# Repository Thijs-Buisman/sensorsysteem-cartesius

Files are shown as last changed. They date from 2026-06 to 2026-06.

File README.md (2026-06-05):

# Sensorsysteem – Wijk Cartesius, Utrecht

> Automatisch passantentelsysteem op basis van een lasersensor met fotodiode.  
> Ontwikkeld in het kader van het QUEST-project **"Gezond leven in Cartesius"** – Hogeschool Utrecht, 2026.

---

## Wat doet dit systeem?

Dit systeem telt automatisch hoeveel voetgangers, fietsers en auto's er door een doorgang in de wijk Cartesius (Utrecht) passeren. De data wordt lokaal opgeslagen op een SD-kaart als CSV-bestand, voorzien van een tijdstempel via een RTC-module.

Het systeem bestaat uit twee onderdelen:
- **Zender** – een lasermodule die een onzichtbare laserstraal uitzendt
- **Ontvanger** – een fotodiode die registreert wanneer de laserstraal wordt onderbroken

Wanneer iemand de straal onderbreekt, classificeert het systeem de passage als voetganger, fietser of auto op basis van de duur en het patroon van de onderbreking.

---

## Resultaten veldtest (21 mei 2026)

| Gebruikerstype | Sensor | Handmatig | Afwijking |
|---|---|---|---|
| Voetganger | 50 | 47 | 6,4% |
| Fietser | 28 | 32 | 12,5% |
| Auto | 3 | 0 | – |
| **Totaal** | **81** | **79** | **2,5%**  |

Totale afwijking: **2,5%** — ruim binnen de gestelde eis van maximaal 15%.

---

## Inhoud van deze repository

```
sensorsysteem-cartesius/
│
├── code/
│   ├── Sensor_code_V3.ino       # Definitieve sensorcode (gebruik deze)
│   └── Sensor_code_V2.ino       # Vorige versie, ter referentie
│
├── kicad/
│   ├── PCB_sensor/              # KiCad 9.0 project – sensorprintplaat (ontvanger)
│   └── PCB_laser/               # KiCad 9.0 project – laserprintplaat (zender)
│
├── 3d-ontwerp/                    # STL-bestanden en .itp autodesk inventor van alle 7 behuizingsonderdelen
│
├── testdata/
│   ├── 05201342.CSV        # Ruwe sensordata van de veldtest
│   └── Sensor_validatie_test.xlsx     # Vergelijking sensor vs. handmatige telling
│
└── docs/
    ├── Overdracht_Sensorsysteem_Cartesius.pdf   # Overdrachts document (begin hier)
    ├── Handleiding_Sensorprototype.pdf
    ├── Proof_of_Concept_Sensorsysteem.pdf
    └── PCB-ontwerp_sensor_V1.pdf
```

---

## Benodigde hardware

| Component | Type | Kosten (ca.) |
|---|---|---|
| Microcontroller | Arduino Nano | €4,00 |
| Lasermodule | KY-008 | €1,50 |
| Fotodiode | SGPD5051C6 | €3,50 |
| RTC-module | DS3231 | €4,00 |
| SD-kaartmodule | standaard SPI | €2,50 |
| Protoboard + bedrading | – | €5,00 |
| 3D-print materiaal | PLA, 573 gram | €12,00 |
| Powerbanks (2x) | 5V USB | €20,00 |
| **Totaal** | | **~€83,92** |

---

## Benodigde software

- [Arduino IDE](https://www.arduino.cc/en/software) – voor de sensorcode
- [KiCad 9.0](https://www.kicad.org/) – voor de PCB-schema's en layouts
- [PrusaSlicer](https://www.prusa3d.com/page/prusaslicer_424/) of [Cura](https://ultimaker.com/software/ultimaker-cura/) – voor de 3D-print bestanden
- [Autodesk Inventor](https://www.autodesk.com/nl/products/inventor/overview) - 3D-modelleringssoftware voor ontwerpers en ingenieurs

---

## Snel aan de slag

1. Download of clone deze repository
2. Open `docs/Overdrachts_document_Sensorsysteem_Cartesius.docx` — dit is het startpunt
3. Upload `code/Sensor_code_V3.ino` via Arduino IDE naar een Arduino Nano
4. Volg de plaatsingsinstructies in `docs/Handleiding_Sensorprototype.docx`

---

## Project & opleiding

| | |
|---|---|
| **Project** | Gezond leven in Cartesius |
| **Opdrachtgever** | Hanneke Kruize – Lectoraat Building Future Cities (RAAK PRO) |
| **Opleiding** | GCL/IDE · QUEST 30EC · Hogeschool Utrecht |
| **Auteur** | Thijs Buisman · Studentnummer 1855662 |
| **Groep** | Groep 8 (Boas Janssen, Joost, Kim, Melisa, Stef, Thijs Buisman) |
| **Docentcoach** | Marit Béguin |
| **Jaar** | 2025–2026 |

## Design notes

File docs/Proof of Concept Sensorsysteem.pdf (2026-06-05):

## Proof of Concept Sensorsysteem

Thijs Buisman 1855662 HU

1. Aanleiding en keuze voor de lasersensor
Binnen het onderzoek naar het gebruik van de buitenruimte in de wijk Cartesius was er behoefte aan een methode om passanten continu en objectief te tellen. De handmatige observatiemethode SOPARC levert waardevolle data op, maar is arbeidsintensief en beperkt tot momentopnames. Daarom is onderzocht of sensortechnologie dit proces kon automatiseren.

Bij de keuze voor een geschikte meettechniek zijn meerdere alternatieven overwogen:
- Camera met computer vision: betrouwbaar en nauwkeurig, maar maakt beeldopnames van mensen. Dit stuit op privacybezwaren en is niet AVG-proof voor gebruik in de openbare ruimte.
- PIR-sensor (bewegingssensor): goedkoop en eenvoudig, maar te ongericht. Reageert op warmte en beweging zonder onderscheid te maken tussen verschillende gebruikerstypen.
- Ultrasone sensor (HC-SR04): geschikt voor afstandsmeting, maar minder betrouwbaar bij smalle doorgangen met meerdere passanten tegelijk.
- Lasersensor met fotodiode: nauwkeurig, AVG-proof (geen beeldopname), kostenefficiënt en geschikt voor het detecteren van patronen per gebruikerstype.

De keuze is gevallen op het lasersysteem. Dit systeem werkt volledig anoniem er worden geen beelden gemaakt en geen persoonsgegevens opgeslagen wat aansluit bij de privacy-eisen die gelden voor onderzoek in een woonwijk.

De werking van het systeem is schematisch weergegeven in Figuur 1. Hierin is te zien hoe de laserstraal tussen de laserbron en de fotodetector loopt, en hoe verschillende gebruikerstypen (wandelaar, fietser en auto) elk een herkenbaar onderbrekingspatroon veroorzaken.

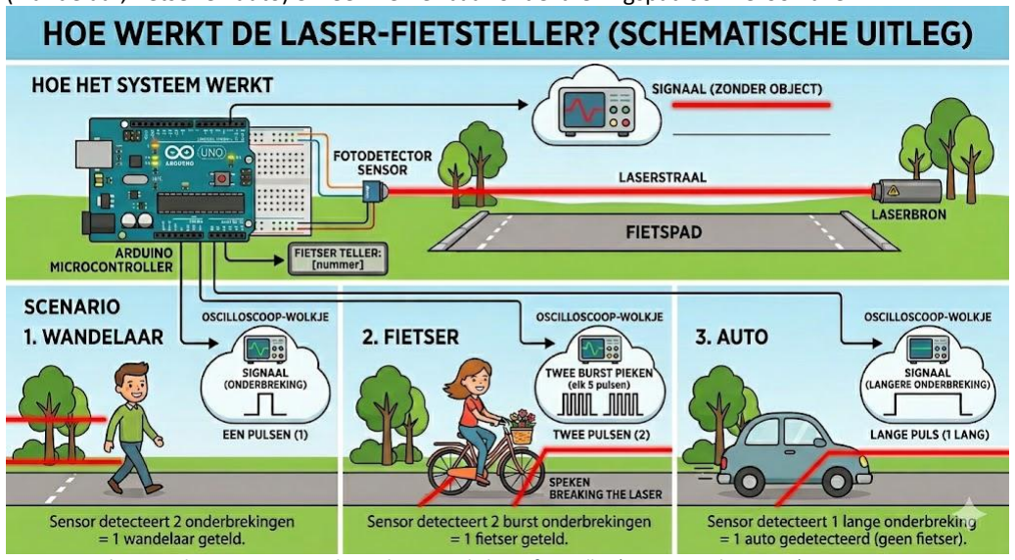
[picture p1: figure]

Figuur 1 - Schematische weergave van de werking van de laser-fietsteller (Bron: nano banana 2)

2. Systeemeisen
Om te kunnen beoordelen of het prototype voldoet aan de gestelde verwachtingen, zijn vooraf systeemeisen opgesteld. Deze eisen zijn geprioriteerd volgens de MoSCoW-methode zo als te zien is in Tabel 1.

Tabel 1 – Eisenlijst sensorsysteem

MoSCoW | Eis
Must have | Het systeem detecteert een onderbreking van de laserstraal betrouwbaar bij minimaal 2 meter afstand tussen laser en fotodiode.
Must have | Elke detectie wordt opgeslagen met een correcte tijdstempel (datum en tijd) op de SD-kaart.
Must have | Het systeem onderscheidt minimaal drie gebruikerstypen: voetganger, fietser en auto.
Must have | Het systeem werkt minimaal 8 uur aaneengesloten op een powerbank van 5000 mAh.
Should have | Het systeem werkt betrouwbaar bij direct zonlicht zonder valse detecties.
Should have | De foutmarge ten opzichte van handmatige telling bedraagt maximaal 15%.
Should have | Het systeem logt geen dubbeltellingen bij één passage.
Could have | Het systeem detecteert de looprichting van een passant.
Could have | De data wordt automatisch geëxporteerd naar een leesbaar CSV-bestand met kolomkoppen.
Won't have | Draadloze datatransmissie (WiFi/LoRa).
Won't have | Realtime monitoring op afstand.
Won't have | Automatische classificatie via machine learning.

3. Componentenkeuze en kostenoverzicht
Op basis van de gekozen meettechniek zijn de benodigde componenten geselecteerd. Daarbij is gelet op beschikbaarheid, prijs en geschiktheid voor buiteninzet. Bewust is gekozen voor een opstelling zonder draadloze verbinding, zodat het systeem volledig zelfstandig functioneert en niet afhankelijk is van een netwerkverbinding. Onderstaande Tabel 2 toont een overzicht van alle onderdelen en de bijbehorende kosten.

Tabel 2 - Kostenoverzicht ontwikkeling prototype

Onderdeel | Specificatie | Kosten
Arduino Nano | Microcontroller voor de verwerking | € 9,99
Laser module KY-008 | Laserbron voor de straalonderbreking | € 1,50
Clock module DS3231 | 2 stuks (voor exacte tijdsregistratie) | € 5,40
Mini SD module | SPI interface voor data-opslag | € 2,27
Micro-SD Kaart 32GB | Lokale data-opslag | € 17,99
Photodiode SGPD5051C6 | 5mm flat lens (detectie van de straal) | € 1,85
Weerstand kit | Diverse componenten voor circuit | € 2,50
Kabel rood/zwart | Solid core 0,25 mm (25m) | € 0,79
Solder board | 2 stuks voor montage | € 1,40
3D print filament | 150 gram (voor behuizing) | € 2,25
Powerbank | 2 stuks (5000 mAh) voor voeding | € 37,98
Totaal | | € 83,92

Opmerking: verzendkosten zijn niet meegenomen omdat een deel van de componenten al in eigen bezit was.

4. Aansluiting en opbouw van het circuit

4.1 Test op breadboard
Voordat de componenten definitief werden gesoldeerd, is de volledige schakeling eerst opgebouwd op een breadboard. Dit maakt het eenvoudig om aansluitingen te testen en fouten te corrigeren zonder schade aan de onderdelen. Tijdens de breadboard-fase is gecontroleerd of:
- De fotodiode het lasersignaal correct ontvangt en verwerkt.
- De RTC-module de juiste tijd doorgeeft aan de Arduino.
- De SD-kaartmodule data wegschrijft zonder fouten.
- De Arduino Nano de signalen correct interpreteert en logt.

Tijdens deze fase is ook een belangrijk probleem ontdekt met de aansluiting van de fotodiode. Eerst was de fotodiode aangesloten op digitale pin D2 met een 1MΩ pull-down weerstand naar GND. Binnen werkte dit correct, maar buiten in direct zonlicht zag het systeem continu een laser terwijl die er niet was. De hoge weerstandswaarde maakte de fotodiode te gevoelig voor omgevingslicht. Dit is opgelost door over te stappen op een 10kΩ pull-down weerstand en de fotodiode aan te sluiten op analoge pin A3. Hierdoor kon in de code een drempelwaarde worden ingesteld waarboven een signaal pas als laser wordt gedetecteerd.

De breadboard-opstelling is te zien in Figuur 2.

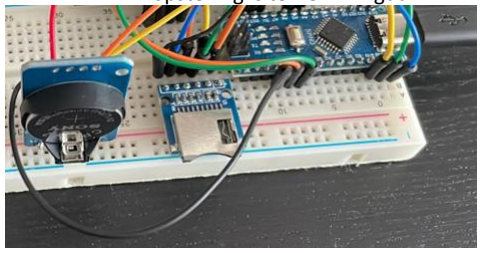
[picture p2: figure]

Figuur 2 – Test sensor schakling op breabord.

4.2 Schematisch ontwerp in KiCad
Het aansluitschema is uitgewerkt in KiCad. Dit schema toont hoe de Arduino Nano, de RTC-module (DS3231), de SD-kaartmodule en de fotodiode op elkaar zijn aangesloten. De schematische weergave is te zien in Figuur 3.

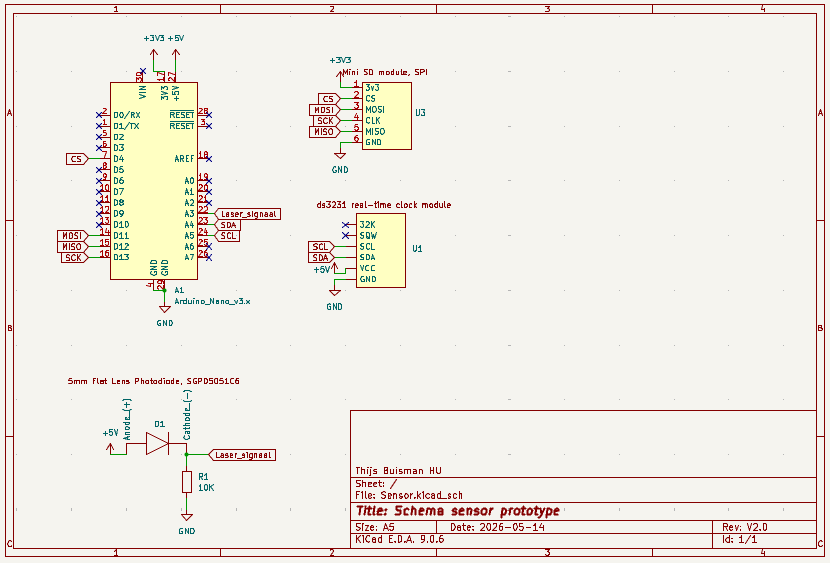
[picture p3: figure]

Figuur 3 - Schema sensor prototype in KiCad

Belangrijkste aansluitingen:
- Fotodiode → analoge ingang A3 van de Arduino Nano, met een 10kΩ pull-down weerstand naar GND.
- RTC DS3231 → I2C-bus (SDA op A4, SCL op A5).
- SD-kaartmodule → SPI-bus (MOSI op D11, MISO op D12, SCK op D13, CS op D10).
- Voeding → 5V en GND van de powerbank via USB naar de Arduino, die de overige modules voedt.

4.3 Solderen op protoboard
Na goedkeuring van het schema zijn de componenten gesoldeerd op een soldeerbordje (protoboard). Hierbij is gebruikgemaakt van solid core kabel (0,25 mm) voor vaste verbindingen. Tijdens het solderen deed zich een complicatie voor: twee RTC DS3231-modules bleken defect te zijn na het solderen. Dit heeft ertoe geleid dat de klokmodule twee keer opnieuw gesoldeerd en vervangen moest worden voordat het systeem correct functioneerde. Dit benadrukt het belang van het testen van componenten vóór definitieve montage. Het gesoldeerde protoboard is te zien in Figuur 4

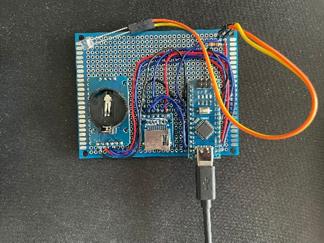
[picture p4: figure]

Figuur 4 - Sensor schakling op protoboard.

5. Behuizing
Voor de behuizing van het sensorsysteem is een modulair ontwerp gekozen. Zowel de zender (laser) als de ontvanger (fotodiode met protoboard) bestaan elk uit vijf onderdelen, waarvan drie identiek zijn. Dit betekent dat deze drie onderdelen onderling verwisselbaar zijn, wat het systeem eenvoudiger maakt om te produceren en te onderhouden.

De gedeelde onderdelen zijn de prikker, het tussenstuk en de sensorhouder. De behuizing zelf verschilt per module omdat de ruimte-inwendige eisen anders zijn. Een overzicht van alle onderdelen van de behuizing is te zien in Figuur 5.

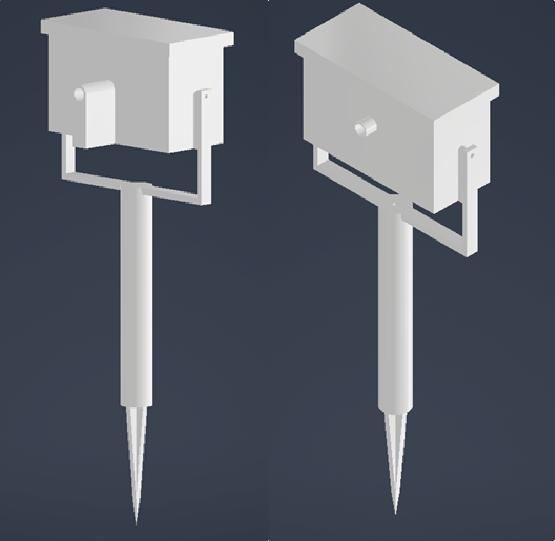
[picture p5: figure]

Figuur 5 - Overzicht van alle onderdelen van de behuizing

Onderdeel 1 - De prikker
De prikker is een spits toelopend onderdeel dat in de grond wordt gestoken, vergelijkbaar met de pennen van buitenlampen zo als te zien is in Figuur 6. Dit zorgt voor een stabiele en rechte plaatsing in de buitenomgeving zonder dat er geboord of geschroefd hoeft te worden in bestaande constructies.

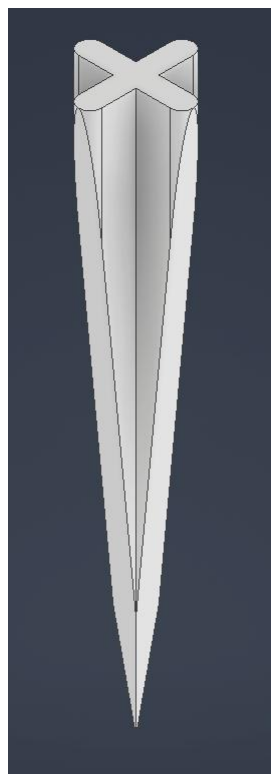
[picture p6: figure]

Figuur 6 - De prikker

Onderdeel 2 - Het tussenstuk
Het tussenstuk is cilindrisch van vorm en verbindt de prikker met de rest van de opstelling zo als te zien is in Figuur 7. Het zorgt ervoor dat de zender en ontvanger op de juiste hoogte komen te staan om ook auto's betrouwbaar te kunnen detecteren. Aan de onderkant past de prikker in het tussenstuk. Aan de bovenkant zit een gat voor een heat insert, zodat er een schroefdraadverbinding ontstaat waarmee de sensorhouder horizontaal verstelbaar is.

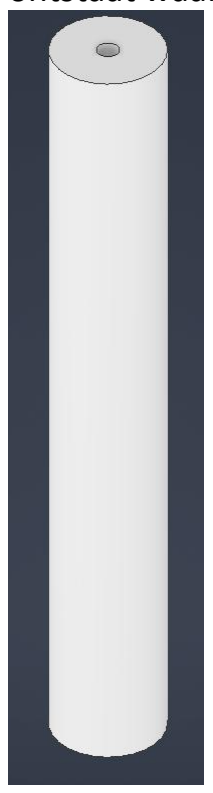
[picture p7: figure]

Figuur 7 - Het tussenstuk

Onderdeel 3 - De sensorhouder
De sensorhouder verbindt het tussenstuk met de behuizing van de sensor. Hij heeft drie gaten: twee voor de bevestiging aan het tussenstuk en één om de behuizing van de sensor zelf te kunnen kantelen. Door deze kantelverbinding kunnen zowel de zender als de ontvanger nauwkeurig op elkaar worden gericht, wat essentieel is voor een betrouwbare laserverbinding over langere afstanden. De sensorhouder is te zien in Figuur 8.

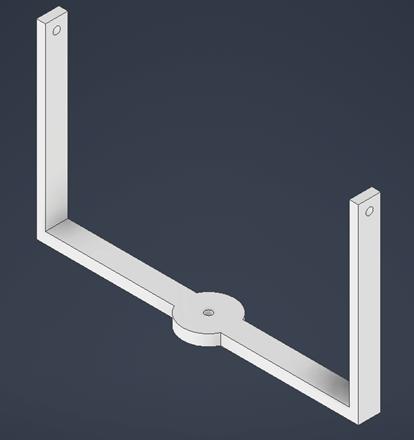
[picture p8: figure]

Figuur 8 - De sensorhouder

Onderdeel 4-5a - Behuizing ontvanger (fotodiode + protoboard)
De behuizing van de ontvanger is de grootste van de twee sensorbehuizingen. Aan de zijkant zitten twee gaten met heat inserts voor bevestiging aan de sensorhouder. De voorkant heeft een verlengde loop, vergelijkbaar met een kokertje, om direct invallend zonlicht zoveel mogelijk te weren. Dit vermindert valse detecties door omgevingslicht. Binnenin is ruimte voor de powerbank, het protoboard en de bedrading. Aan de onderkant zit een uitsparing waar een schakelaar in past om het systeem van stroom te voorzien. De behuizing wordt afgesloten met een passend deksel. De behuizing van de ontvanger is te zien in Figuur 9.

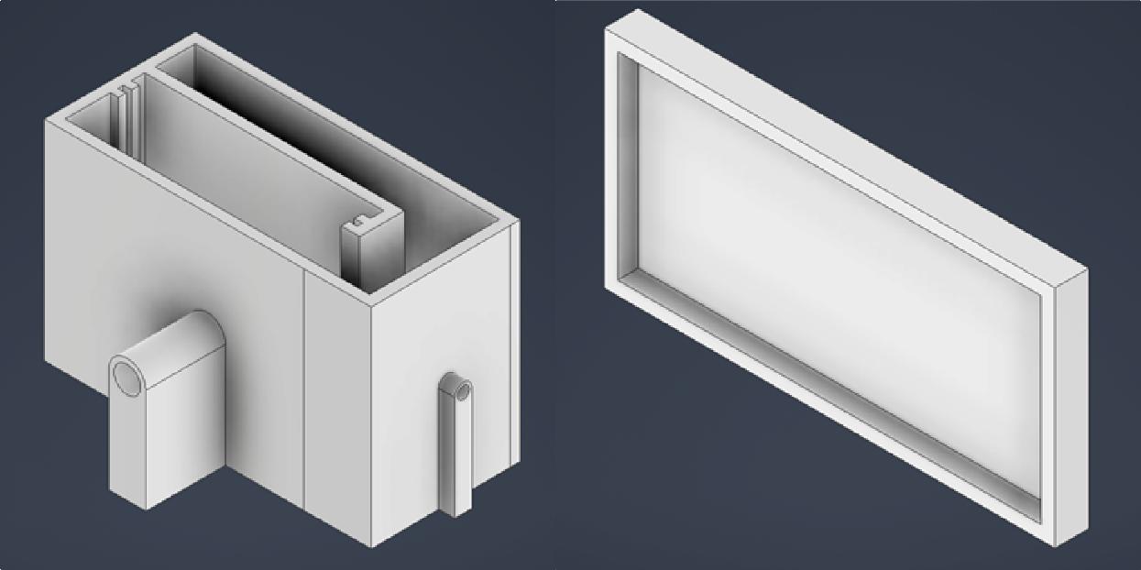
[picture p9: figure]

Figuur 9 - Behuizing ontvanger

Onderdeel 4-5b - Behuizing zender (laser)
De behuizing van de zender lijkt sterk op die van de ontvanger en heeft dezelfde bevestigingsgaten met heat inserts aan de zijkant. Omdat er alleen een lasermodule, een powerbank en een schakelaar in zitten, is deze behuizing compacter dan die van de ontvanger. Ook deze behuizing wordt afgesloten met een passend deksel. De behuizing van de zender is te zien in Figuur 10.

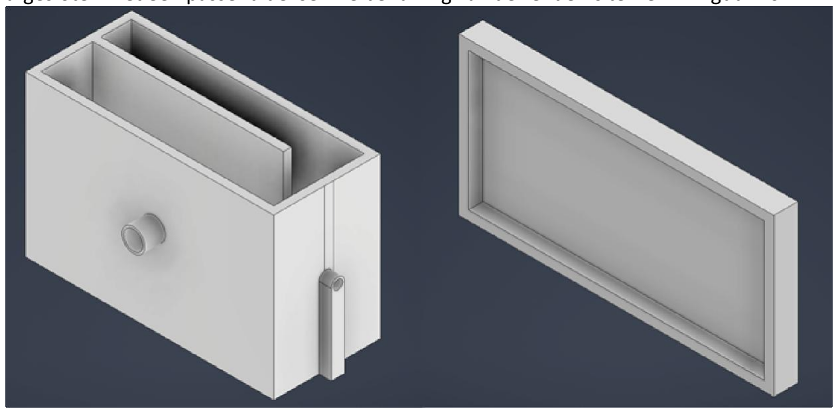
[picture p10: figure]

Figuur 10 - Behuizing zender

Ontwerpiteraties
Tijdens het 3D-printen van de behuizing zijn twee onderdelen aangepast op basis van praktische problemen die ontstonden bij de eerste printpoging.

Het tussenstuk (onderdeel 2) was in het oorspronkelijke ontwerp cilindrisch van vorm. De printer had moeite met het correct printen van deze ronde geometrie, waardoor het onderdeel niet bruikbaar uit de printer kwam. Als oplossing is de vorm aangepast van cilindrisch naar vierkant. Dit maakte het onderdeel beter printbaar zonder dat de functionaliteit verloren ging.

De sensorhouder (onderdeel 3) bleek na de eerste print te dun en daardoor niet sterk genoeg om de behuizing stabiel te houden. Om dit op te lossen is de wanddikte vergroot, waardoor het onderdeel voldoende stevigheid kreeg voor gebruik in de buitenomgeving.

De definitieve versie van alle onderdelen na deze aanpassingen is te zien in Figuur 11.

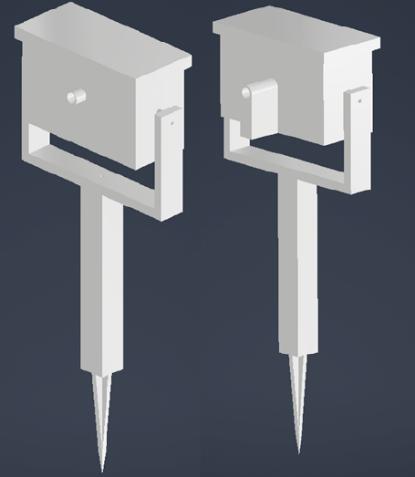
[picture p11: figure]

Figuur 11 - Definitieve onderdelen na ontwerpiteraties

Printoverzicht behuizing
Alle onderdelen zijn geprint met PLA-filament op een Ender V3 SE. Onderstaande Tabel 3 geeft een overzicht van het materiaalverbruik en de printtijd per onderdeel.

Tabel 3 - Printoverzicht behuizing

Onderdeel | Aantal | Materiaal per stuk (PLA) | Printtijd per stuk | Printer
Onderdeel 1 - De prikker | 2x | 8 gram | 1:31 uur | Ender V3 SE
Onderdeel 2 - Het tussenstuk | 2x | 52 gram | 3:00 uur | Ender V3 SE
Onderdeel 3 - De sensorhouder | 2x | 45 gram | 4:03 uur | Ender V3 SE
Onderdeel 4a - Behuizing ontvanger | 1x | 153 gram | 14:47 uur | Ender V3 SE
Onderdeel 4b - Behuizing zender | 1x | 140 gram | 13:19 uur | Ender V3 SE
Onderdeel 5a - Deksel ontvanger | 1x | 36 gram | 2:05 uur | Ender V3 SE
Onderdeel 5b - Deksel zender | 1x | 34 gram | 1:58 uur | Ender V3 SE
Totaal | 10 prints | 573 gram | ±49:17 uur | -

Resultaat
Na het printen en assembleren van alle onderdelen is het complete sensorsysteem tot stand gekomen. Onderstaande afbeelding Figuur 12 tonen het eindresultaat van zowel de zender als de ontvanger in de praktijk.

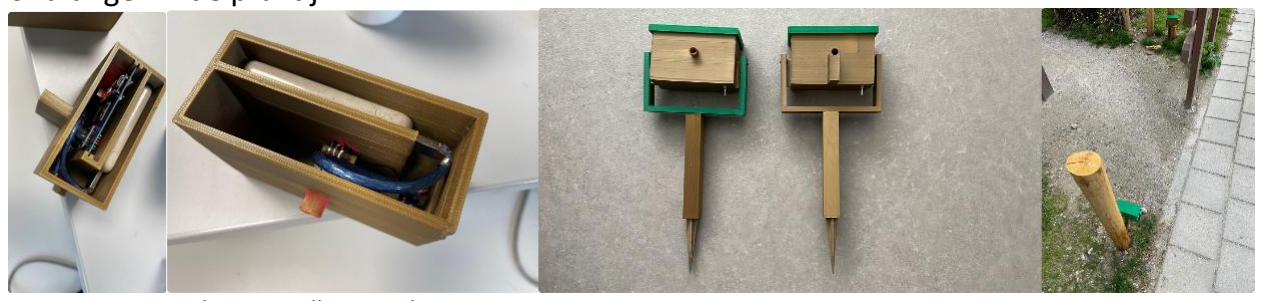
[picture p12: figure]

Figuur 12 - Complete opstelling zender en ontvanger

6. Ontwikkeling van de code

6.1 Losse component tests
Voordat de volledige code werd geschreven, zijn alle drie de modules eerst afzonderlijk getest in aparte Arduino-sketches. Voor de fotodiode is getest of de analoge waarden correct binnenkwamen via de Serial Monitor. De RTC DS3231 is getest op correcte tijdregistratie en de SD-kaartmodule is getest op het aanmaken en wegschrijven van een testbestand. Door componenten los te testen konden fouten per module worden opgespoord zonder dat andere onderdelen storing veroorzaakten.

6.2 Sensor Code V1 - eerste integratie
Na de losse tests zijn alle modules samengevoegd tot één werkende code: Sensor Code V1. De belangrijkste keuzes in V1 waren:
- De fotodiode was aangesloten op digitale pin D2 en werd uitgelezen met digitalRead().
- Het logbestand had een vaste naam: LOG.CSV.
- Detectie was gebaseerd op drie patronen: een lange onderbreking voor een auto, meerdere snelle onderbrekingen voor een fietser en een korte onderbreking voor een voetganger.

6.3 Sensor Code V2 - verbeteringen
Tijdens het testen van V1 buiten bleek dat de fotodiode te gevoelig was voor zonlicht, waardoor het systeem continu een laser registreerde terwijl die er niet was. Dit leidde tot de volgende verbeteringen in V2:
- Overstap van digitalRead() op analogRead() op pin A3, zodat een instelbare drempelwaarde (LASER_THRESHOLD) bepaalt wanneer de laser als aanwezig wordt beschouwd.
- Toevoeging van MIN_BREAK_DURATION om ruis en trillingen te filteren: onderbrekingen korter dan 20ms worden genegeerd.
- Het logbestand krijgt automatisch een naam op basis van datum en tijd van inschakelen, zodat meerdere meetmomenten te onderscheiden zijn.
- De sensorwaarde wordt nu ook geprint in de Serial Monitor voor eenvoudiger debuggen.

De werking van V2 is schematisch weergegeven in Figuur 13.

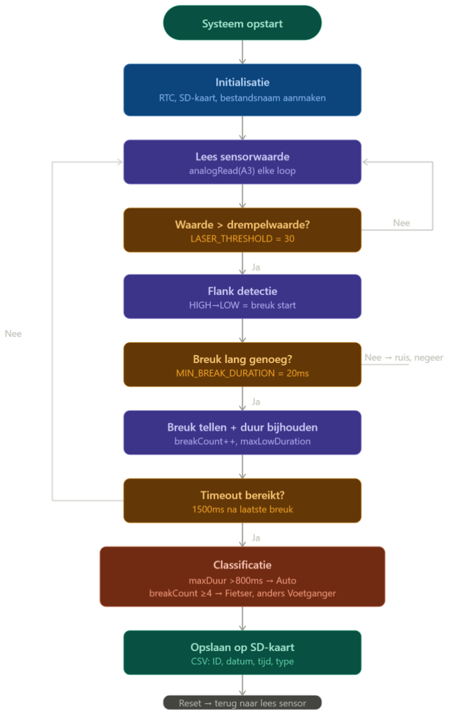
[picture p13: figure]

Figuur 13 - Flowchart sensor code v2

5.4 Sensor Code V3 - verbeterde code volgens richtlijnen
Na het ontwikkelen van V2 is de code herschreven naar V3 volgens de C-coding richtlijnen van de opleiding. De belangrijkste verbeteringen zijn:
- Alle constanten staan als #define bovenaan in hoofdletters, zodat direct zichtbaar is dat het om instellingen gaat.
- Elke functie heeft een documentatieblok met beschrijving, argumenten en returnwaarde.
- Bovenaan het bestand staat een volledige bestandsdocumentatie met naam, auteur, versie en beschrijving.
- De loop() functie bevat alleen nog functieaanroepen. Alle logica zit in aparte, herbruikbare functies.
- Globale variabelen beginnen met een g zodat direct zichtbaar is dat het globale variabelen zijn.
- Functieprototypes staan bovenaan zodat de volgorde van functies vrij is.
- Accolades staan lijnrecht onder elkaar met 4 spaties inspringing.

De code is opgesplitst in de volgende functies in Tabel 4:

Tabel 4 – Functies code

Functie | Beschrijving
initRTC() | Initialiseert de klokmodule
initSD() | Initialiseert de SD-kaartmodule
initLogFile() | Maakt logbestand aan met datum/tijd naam
readSensor() | Leest fotodiode en vergelijkt met drempelwaarde
handleBreakStart() | Verwerkt start van een laseronderbreking
handleBreakEnd() | Verwerkt einde van een onderbreking, filtert ruis
updateMaxDuration() | Houdt maximale breukduur bij
checkTimeout() | Controleert of evaluatiemoment bereikt is
classifyObject() | Classificeert passant als voetganger, fietser of auto
logData() | Schrijft detectie weg naar CSV op SD-kaart
resetMeting() | Reset alle variabelen voor volgende passage

De volledige code is te zien hieronder:

/*
*
=========================================================================== ==
* Sensor_code_V3.ino
* Auteur | : Thijs Buisman
* Versie | : 3.0
* Datum | : 2026
* -----------------------------------------------------------------------------
* Beschrijving:
* | Geautomatiseerd passantenmeetsysteem voor de buitenruimte van wijk
* | Cartesius. Het systeem detecteert onderbrekingen van een laserstraal
* | via een fotodiode en classificeert passanten als voetganger, fietser
* | of auto op basis van onderbrekingspatronen. Data wordt met tijdstempel
* | weggeschreven naar een CSV-bestand op een SD-kaart.
*
* Hardware:
* | - Arduino Nano
* | - Fotodiode op pin A3 met 10kOhm pull-down weerstand
* | - RTC DS3231 op I2C (SDA=A4, SCL=A5)
* | - SD-kaartmodule op SPI (MOSI=D11, MISO=D12, SKC=D13, CS=D4)
*
* Versiebeheer:
* | V1 - Eerste werkende integratie, digitalRead op D2
* | V2 - analogRead op A3, drempelwaarde, dynamische bestandsnaam
* | V3 - Modulaire opbouw, C-coding richtlijnen, functieprototypes

*
=========================================================================== ==
*/

#include <SPI.h>

#include <SD.h>

#include <Wire.h>

#include <RTClib.h>

/* --- Pin definities --- */
#define SENSOR_PIN | A3

#define SD_CS_PIN | 4

/* --- Sensor drempelwaarden --- */
#define LASER_THRESHOLD | 25 | /* Analoge waarde waarboven laser

aanwezig is */
#define MIN_BREAK_DURATION 20 | /* Minimale breukduur in ms, korter =

ruis | */

/* --- Detectie instellingen --- */
#define CAR_MIN_DURATION | 800 | /* Breukduur > 800ms =

auto | */
#define BIKE_MIN_INTERRUPTS 4 | /* 4 of meer breuken =

fietser | */
#define TIMEOUT_MS | 1500 /* Wachttijd na laatste breuk voor

evaluatie | */

/* --- Overige instellingen --- */
#define SENSOR_ID "0x001b"

#define CSV_HEADER "SensorID;Datum;Tijd;GedetecteerdObject"

/* --- Globale variabelen --- */
RTC_DS3231 | rtc;
char | gLogFile[13];
bool | gIsMeasuring;
bool | gLastSensorState;
unsigned long gCurrentLowStart; unsigned long gMaxLowDuration; unsigned long gLastInterruptTime;
int | gBreakCount;

/* --- Functieprototypes --- */
void | initRTC(void);
void | initSD(void);
void | initLogFile(void);
bool | readSensor(void);
void | handleBreakStart(unsigned long currentTime);

void | handleBreakEnd(unsigned long currentTime);
void | updateMaxDuration(unsigned long currentTime);
bool | checkTimeout(unsigned long currentTime);
String classifyObject(void);
void | logData(String type);
void | resetMeting(void);

/*
* setup()
* Initialiseert alle hardware modules bij opstarten. * Wordt eenmalig uitgevoerd na inschakelen of reset. */
void setup()
{
Serial.begin(9600);
gIsMeasuring | = false;
gLastSensorState | = HIGH;
gCurrentLowStart | = 0;
gMaxLowDuration | = 0;
gLastInterruptTime = 0;
gBreakCount | = 0;
initRTC();
initSD();
initLogFile();
Serial.println("Systeem klaar voor detectie."); }

/*
* loop()
* Hoofdlus: leest sensor, verwerkt flanken en evalueert na timeout. */
void loop()
{
bool | currentSensorState = readSensor();
unsigned long currentTime | = millis();

if (gLastSensorState == HIGH && currentSensorState == LOW) handleBreakStart(currentTime);

if (gLastSensorState == LOW && currentSensorState == HIGH) handleBreakEnd(currentTime);

if (gIsMeasuring && currentSensorState == LOW) updateMaxDuration(currentTime);

if (gIsMeasuring && currentSensorState == HIGH && checkTimeout(currentTime))
{

String objectType = classifyObject(); logData(objectType);
resetMeting();
}

gLastSensorState = currentSensorState; }

/*
* initRTC()
* Initialiseert de RTC DS3231 klokmodule via I2C.
* Bij stroomverlies wordt tijd ingesteld op compileer-tijdstip. */
void initRTC(void)
{
if (!rtc.begin())
{
Serial.println("FOUT: RTC niet gevonden!"); while (1);
}
if (rtc.lostPower())
{
Serial.println("RTC: stroom verloren, tijd hersteld."); rtc.adjust(DateTime(F(__DATE__), F(__TIME__)));
}
}

/*
* initSD()
* Initialiseert de SD-kaartmodule via SPI.
* Stopt het programma als de module niet gevonden wordt. */
void initSD(void)
{
Serial.print("SD-kaart initialiseren..."); if (!SD.begin(SD_CS_PIN))
{
Serial.println(" MISLUKT!");
while (1);
}
Serial.println(" gelukt.");
}

/*
* initLogFile()
* Maakt logbestand aan met naam op basis van datum en tijd. * Bestandsnaam formaat: MMDDHHII.CSV (FAT32 max 8.3)
*/

void initLogFile(void)
{
DateTime now = rtc.now();
sprintf(gLogFile, "%02d%02d%02d%02d.CSV", now.month(), now.day(), now.hour(), now.minute()); Serial.print("Logbestand: "); Serial.println(gLogFile);
if (!SD.exists(gLogFile))
{
File logFile = SD.open(gLogFile, FILE_WRITE); if (logFile)
{
logFile.println(CSV_HEADER); logFile.close();
}
}
}

/*
* readSensor()
* Leest analoge waarde fotodiode, vergelijkt met drempelwaarde. * Returnvalue: TRUE als laser aanwezig, FALSE als onderbroken */
bool readSensor(void)
{
int waarde = analogRead(SENSOR_PIN);
return (waarde > LASER_THRESHOLD) ? HIGH : LOW; }

/*
* handleBreakStart()
* Verwerkt het moment waarop de laserstraal wordt onderbroken. * Arguments: currentTime - huidige millis() waarde
*/
void handleBreakStart(unsigned long currentTime)
{
if (!gIsMeasuring)
{
gIsMeasuring | = true;
gBreakCount | = 0;
gMaxLowDuration = 0;
}
gBreakCount++;
gCurrentLowStart = currentTime; gLastInterruptTime = currentTime; }

/*

* handleBreakEnd()
* Verwerkt het moment waarop de laserstraal herstelt.
* Breuken korter dan MIN_BREAK_DURATION worden als ruis genegeerd. * Arguments: currentTime - huidige millis() waarde
*/
void handleBreakEnd(unsigned long currentTime)
{
if (!gIsMeasuring)
return;

unsigned long lowDuration = currentTime - gCurrentLowStart;

if (lowDuration >= MIN_BREAK_DURATION)
{
if (lowDuration > gMaxLowDuration) gMaxLowDuration = lowDuration; gLastInterruptTime = currentTime; }
else
gBreakCount--;
}

/*
* updateMaxDuration()
* Houdt maximale breukduur bij tijdens actieve onderbreking. * Arguments: currentTime - huidige millis() waarde
*/
void updateMaxDuration(unsigned long currentTime)
{
unsigned long currentDuration = currentTime - gCurrentLowStart; if (currentDuration > gMaxLowDuration)
gMaxLowDuration = currentDuration;
}

/*
* checkTimeout()
* Controleert of wachttijd na laatste breuk verstreken is. * Returnvalue: TRUE als timeout bereikt, anders FALSE
* Arguments: currentTime - huidige millis() waarde
*/
bool checkTimeout(unsigned long currentTime)
{
return (currentTime - gLastInterruptTime > TIMEOUT_MS); }

/*
* classifyObject()
* Classificeert gedetecteerd object op basis van breukpatroon.

* Returnvalue: String "Auto", "Fietser" of "Voetganger" */
String classifyObject(void)
{
String objectType;

if (gMaxLowDuration > CAR_MIN_DURATION) objectType = "Auto";
else if (gBreakCount >= BIKE_MIN_INTERRUPTS) objectType = "Fietser";
else
objectType = "Voetganger";

Serial.print("Detectie: "); Serial.print(objectType);
Serial.print(" | Breuken: "); Serial.print(gBreakCount);
Serial.print(" | Max duur: "); Serial.print(gMaxLowDuration);
Serial.println("ms");

return objectType;
}

/*
* logData()
* Schrijft detectieregel naar CSV-logbestand op SD-kaart. * Formaat: SensorID;Datum;Tijd;GedetecteerdObject
* Arguments: type - gedetecteerd objecttype als String */
void logData(String type)
{
DateTime now = rtc.now();
char dateBuffer[12];
char timeBuffer[10];

sprintf(dateBuffer, "%04d-%02d-%02d", now.year(), now.month(), now.day());
sprintf(timeBuffer, "%02d:%02d:%02d", now.hour(), now.minute(), now.second());

String logString = String(SENSOR_ID) + ";" + dateBuffer + ";" + timeBuffer + ";" + type;

File logFile = SD.open(gLogFile, FILE_WRITE);
if (logFile)
{
logFile.println(logString);
logFile.close();
Serial.println("Opgeslagen in: " + String(gLogFile)); }

else
Serial.println("FOUT: kan bestand niet openen: " + String(gLogFile));
}

/*
* resetMeting()
* Reset alle metvariabelen voor de volgende passage. */
void resetMeting(void)
{
gIsMeasuring = false;
}

7. Testen & resultaten

7.1 Testopstelling
Op 21 mei 2026 is het sensorprototype gedurende vier uur getest in de buitenruimte van Cartesius bij de doorgang van deelgebied 2. De test vond plaats tussen 14:45 en 18:45 onder bewolkte en droge weersomstandigheden. De afstand tussen de laser en de fotodiode bedroeg circa 2 meter. Tijdens de test is één observator ter plaatse gebleven om tegelijkertijd handmatig te registreren wat er door de doorgang passeerde via de SOPARC-webapp. Op die manier kon de sensordata achteraf worden vergeleken met de handmatige tellingen.

In Figuur 14 is de testopstelling weergegeven. Links is op de satellietfoto te zien waar de sensor is neergezet bij de doorgang van deelgebied 2. In het midden is de fysieke opstelling van de sensor op locatie te zien. Rechts is de SOPARC-webapp te zien waarmee de observator tijdens de test handmatig kon registreren wat er door de doorgang passeerde door op de knoppen te drukken.

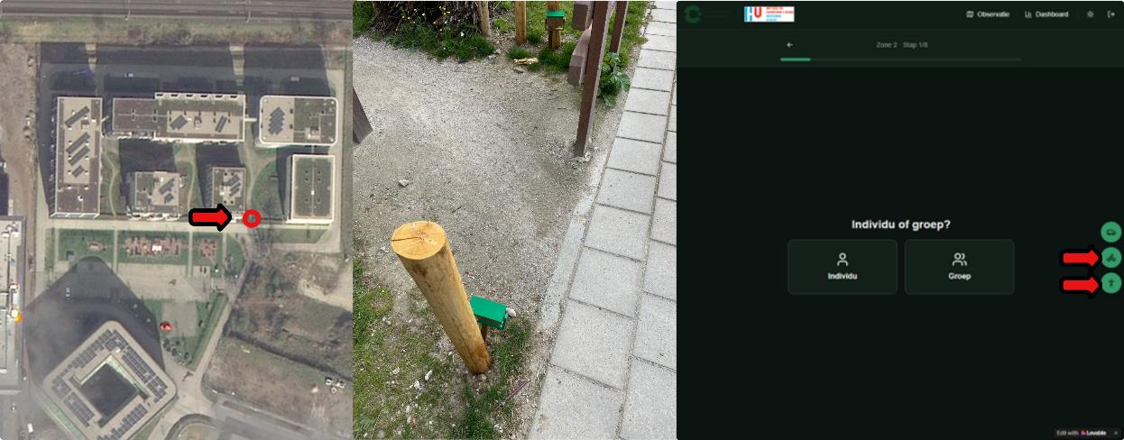
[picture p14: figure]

Figuur 14 - Testopstelling: locatie (links), sensoropstelling op locatie (midden) en SOPARC-webapp voor validatie (rechts)

7.2 Resultaten
Om de nauwkeurigheid van het prototype te kunnen beoordelen, zijn de CSV-data van de sensor en de handmatige registraties uit de SOPARC-webapp naast elkaar gelegd in een Excel-bestand. Beide datasets bevatten per passage een tijdstempel en een gebruikerstype, waardoor de registraties op volgorde vergeleken konden worden. Een screenshot van dit overzicht is te zien in Figuur 15.

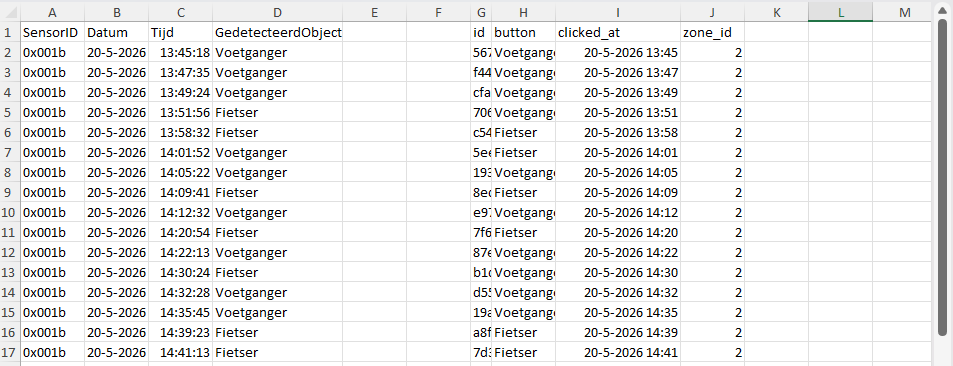
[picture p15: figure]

Figuur 15 - Screenshot van de samengevoegde sensor- en webapp-data in Excel

Uit deze vergelijking kwamen de volgende resultaten naar voren. De sensor registreerde in totaal 81 passages, de handmatige telling via de webapp telde 79 passages. De resultaten per gebruikerstype zijn weergegeven in

Tabel 5 en
Tabel 6.

Tabel 5 - Sensordata: geregistreerde passages

Gebruikerstype | Aantal
Voetganger | 50
Fietser | 28
Auto | 3
Totaal | 81

Tabel 6 - Handmatige telling via webapp: geregistreerde passages

Gebruikerstype | Aantal
Voetganger | 47
Fietser | 32
Auto | 0
Totaal | 79

7.3 Vergelijking en nauwkeurigheid
Door de twee datasets naast elkaar te leggen, kan per gebruikerstype worden bepaald hoe nauwkeurig de sensor heeft gepresteerd. Dit is weergegeven in Tabel 7.

Tabel 7 - Vergelijking sensor vs. handmatige telling

Gebruikerstype | Sensor | Handmatig | Verschil | Afwijking
Voetganger | 50 | 47 | +3 | 6,4%
Fietser | 28 | 32 | -4 | 12,5%
Auto | 3 | 0 | +3 | —
Totaal | 81 | 79 | +2 | 2,5%
Voor voetgangers en fietsers presteert de sensor redelijk goed. Het totale verschil van 2 passages op 79 geregistreerde passages komt neer op een afwijking van 2,5%, wat binnen de gestelde eis van maximaal 15% foutmarge valt. Per gebruikerstype liggen de afwijkingen echter hoger: voor voetgangers bedraagt de afwijking 6,4% en voor fietsers 12,5%. De fietserdetectie zit daarmee dicht tegen de grens van 15% aan.

De drie geregistreerde auto's verdienen extra toelichting. De handmatige observator heeft geen auto's genoteerd in de webapp, wat betekent dat de sensor deze passages fout heeft geclassificeerd. Mogelijk gaat het om fietsers of voetgangers de laser langdurig blokkeerden, waardoor de sensor dit interpreteerde als een auto. Dit is een bekend beperkingspunt van het huidige classificatiealgoritme dat uitsluitend kijkt naar de duur van de onderbreking.

De vier gemiste fietsers aan de kant van de sensor kunnen verklaard worden doordat niet alle fietsen dezelfde spaakpatronen hebben. Fietsen met weinig of dicht op elkaar staande spaken genereren minder onderbrekingen, waardoor de sensor deze soms classificeert als voetganger in plaats van fietser.

7.4 Toetsing aan systeemeisen
Op basis van de testresultaten kan worden beoordeeld in hoeverre het prototype voldoet aan de vooraf opgestelde systeemeisen. Dit is weergegeven in Tabel 8.

Tabel 8 - Toetsing systeemeisen

MoSCoW | Eis | Resultaat | Toelichting
Must have | Betrouwbare detectie bij minimaal 2 meter afstand | ✓ | De sensor functioneerde correct op een afstand van 1 tot 2 meter.
Must have | Elke detectie opgeslagen met correcte tijdstempel op SD-kaart | ✓ | Alle 81 passages zijn correct weggeschreven met datum en tijd.
Must have | Onderscheid tussen minimaal drie gebruikerstypen | ✓ | Het systeem classificeert voetgangers, fietsers en auto's.
Must have | Minimaal 8 uur werken op powerbank van 5000 mAh | ✓ | Het systeem heeft de volledige testduur van 4 uur zonder onderbreking gefunctioneerd. De berekende batterijduur bedraagt circa 40 uur.
Should have | Betrouwbaar werken bij direct zonlicht zonder valse detecties | ✓ | De test vond plaats bij bewolkt weer. Bij eerdere tests buiten zonder kokertje traden wel valse detecties op door zonlicht. Dit is opgelost met de analoge drempelwaarde.
Should have | Foutmarge maximaal 15% ten opzichte van handmatige telling | ✓ | De totale afwijking bedraagt 2,5%. Per type: voetganger 6,4%, fietser 12,5%. Beide vallen binnen de gestelde grens.
Should have | Geen dubbeltellingen bij één passage | ✗ | Door de hold-off tijd en minimale breukduur zijn geen dubbeltellingen waargenomen. Toch zijn er 2 extra meting gemten.
Could have | Detectie van looprichting | ✗ | Niet geïmplementeerd in dit prototype. Vereist een tweede sensormodule.
Could have | Automatische export naar leesbaar CSV met kolomkoppen | ✓ | Het systeem maakt automatisch een CSV-bestand aan met kolomkoppen en een bestandsnaam op basis van datum en tijd.
Won't have | Draadloze datatransmissie | — | Buiten scope voor dit prototype.
Won't have | Realtime monitoring op afstand | — | Buiten scope voor dit prototype.
Won't have | Automatische classificatie via machine learning | — | Buiten scope voor dit prototype.

Alle must have eisen zijn behaald. Van de drie should have eisen zijn er twee behaald, waarvan de fietser detectie met 12,5% dicht tegen de gestelde grens van 15% aanligt. De enige could have eis die niet is gerealiseerd is de richting detectie, waarvoor een tweede sensormodule nodig is.

8. Conclusie
Het sensorprototype heeft tijdens de test op 21 mei 2026 aangetoond dat geautomatiseerde passantentelling met een lasersysteem in de buitenruimte van Cartesius haalbaar is. Alle must have eisen zijn behaald en de totale foutmarge van 2,5% valt ruim binnen de gestelde grens van 15%. Het systeem heeft gedurende de volledige testperiode van vier uur zelfstandig gefunctioneerd zonder storingen of dataverlies.

Toch zijn er ook beperkingen zichtbaar geworden. De fietserdetectie zit met een afwijking van 12,5% dicht tegen de grens aan, de sensor heeft drie passages fout geclassificeerd als auto, en de eis rondom dubbeltellingen is niet volledig behaald doordat het totale aantal registraties twee hoger uitvalt dan de handmatige telling. Dit betekent dat het systeem als proof of concept werkt, maar nog niet nauwkeurig genoeg is voor zelfstandige inzet zonder handmatige controle.

Of het systeem ook betrouwbaar werkt bij direct zonlicht, regen en harde wind kon in deze testopstelling niet worden vastgesteld omdat de test plaatsvond bij bewolkt en droog weer. Voor definitieve conclusies over de betrouwbaarheid in alle weersomstandigheden is aanvullend testen nodig.

Desondanks laat dit prototype zien dat een eenvoudig en kostenefficiënt lasersysteem in staat is om met beperkte middelen betrouwbare teldata te genereren. Het vormt daarmee een solide eerste stap richting een volwaardige sensor die in de toekomst, met de aanbevolen doorontwikkelingen, zelfstandig en continu ingezet kan worden voor het meten van het gebruik van de buitenruimte in Cartesius.

9. Aanbeveling

9.1 Beperkingen van het huidige prototype
Tijdens de test zijn een aantal beperkingen naar voren gekomen die de inzetbaarheid van het huidige prototype in de praktijk beperken. Deze zijn hieronder samengevat.

De behuizing is te zwaar en te groot, waardoor het systeem instabiel wordt bij harde wind en makkelijk kan omvallen. De prikker is van kunststof, waardoor die op harde ondergrond niet goed de grond in gaat zonder eerst een gat te maken met gereedschap. Het correct richten van de laser op de fotodiode kost veel tijd en is nauwkeurig werk, wat het plaatsen van de sensor omslachtig maakt. De maximale meetafstand bedraagt circa twee meter omdat de laserbundel daarna te veel uitspreidt en de fotodiode het signaal niet meer betrouwbaar oppikt. De behuizing is niet waterdicht, waardoor meten bij regen niet mogelijk is. Het systeem kan niet onderscheiden of er meerdere personen of fietsers naast elkaar door de doorgang lopen, wat leidt tot ondertelling bij drukte. Tot slot kunnen dieren zoals katten of honden ook door de laserstraal lopen en worden dan geregistreerd als passant, wat de data kan vertekenen.

9.2 Oplossingen en verbeteringen
Voor elk van de genoemde beperkingen zijn verbeteringen mogelijk die in een volgende versie van het prototype doorgevoerd kunnen worden.

De behuizing kan lichter en compacter worden gemaakt door over te stappen op een PCB in plaats van een protoboard, zie sectie 9.3. Een smallere behuizing vangt minder wind en is stabieler. De prikker kan worden vervangen door een metalen variant of de sensor kan worden bevestigd aan een bestaand hekwerk of paal, wat zowel stabieler als eenvoudiger te plaatsen is.

Het richten kan eenvoudiger worden gemaakt door een verstelbaar scharnierend mechanisme met vergrendeling toe te voegen aan de sensorhouder, zodat de laser in één beweging gericht en vergrendeld kan worden. Een indicatie-LED of buzzer die aangeeft wanneer de laser de fotodiode correct raakt zou dit proces verder vereenvoudigen.

De meetafstand kan worden vergroot door een gefocuste lasermodule te gebruiken of een lens toe te voegen voor de fotodiode, zodat de bundel minder uitspreidt over langere afstanden.

Voor waterdichtheid is een behuizing met minimaal IP65-certificering nodig. Dit betekent dat alle openingen zoals de schakelaaruitsparing en de lensopening worden afgedicht met rubberringen of een transparante afdekking.

De classificatie van gebruikerstypen kan worden verbeterd door een tweede sensormodule parallel aan de eerste te plaatsen. Hiermee kan de breedte van een object worden gemeten, wat helpt bij het onderscheiden van meerdere personen naast elkaar en het uitfilteren van kleine dieren.

9.3 Opschaling: van prototype naar volwaardig meetsysteem
Als de bovengenoemde verbeteringen zijn doorgevoerd, is het systeem geschikt voor bredere inzet in de wijk. De logische vervolgstap is het ontwerpen van een PCB op basis van het KiCad-schema dat voor dit prototype is gemaakt. Een PCB vervangt het protoboard door een compacte, op maat gemaakte printplaat waarop alle componenten direct gesoldeerd zijn. Dit maakt het systeem kleiner, robuuster en eenvoudiger te reproduceren in meerdere exemplaren. Een eerste versie van dit PCB-ontwerp is uitgewerkt in Bijlage G.

Met meerdere identieke sensoren is het mogelijk om op strategische plekken in de wijk te meten. Op basis van de plattegrond van Cartesius zijn in totaal 16 mogelijke meetlocaties geïdentificeerd, verdeeld over vier categorieën op basis van prioriteit en meetdoel. Dit is weergegeven in Figuur 16.

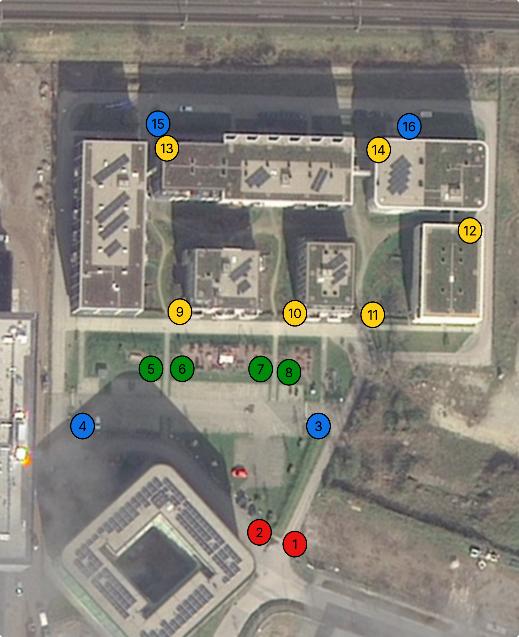
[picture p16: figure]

Figuur 16 - Aanbevolen sensorlocaties in Cartesius, gekleurd per categorie

Rood - hoofdingangen (locaties 1 en 2)
Locaties 1 en 2 bevinden zich bij de hoofdingangen van de wijk, waar op dit moment geen alternatieve route is. Al het verkeer dat de wijk binnenkomt of verlaat passeert langs deze punten, zowel voetgangers, fietsers als auto's. Dit maakt deze locaties het meest waardevol voor een totaalbeeld van het gebruik van de wijk. Met slechts twee sensoren kan hier al een volledig beeld worden verkregen van de totale in- en uitstroom.

Blauw - parkeerlocaties (locaties 3, 4, 15 en 16)
Locaties 3 en 4 zijn geplaatst bij het bestaande parkeerterrein en locaties 15 en 16 bij de parkeergarage. Deze locaties zijn relevant als het autogebruik specifiek in kaart gebracht moet worden. Voor algemeen onderzoek naar het gebruik van de buitenruimte zullen deze locaties minder prioriteit hebben, maar ze kunnen wel inzicht geven in hoe vaak bewoners de auto gebruiken ten opzichte van andere vervoersmiddelen.

Groen - moestuin en picknickzone (locaties 5 t/m 8)
Locaties 5 tot en met 8 zijn geplaatst rondom de moestuin en de picknicktafels. Door hier sensoren te plaatsen kan worden gemeten hoe vaak en op welke momenten deze voorzieningen worden bezocht. Dit geeft directe informatie over het gebruik van de recreatieve buitenruimte, wat aansluit bij de Blue Zone-principes die centraal staan in het onderzoek.

Geel - binnenhof deelgebied 2 (locaties 9 t/m 14)
Het binnenhof van deelgebied 2 heeft zes doorgangen. Door op elk van deze doorgangen een sensor te plaatsen kan het volledige gebruik van dit binnengebied in kaart worden gebracht. Omdat alle bewegingen via deze zes punten verlopen, is het met deze sensoren mogelijk om te bepalen hoeveel mensen het binnenhof gebruiken, op welke momenten het druk is en via welke doorgang de meeste mensen binnenkomen.

Door alle 16 locaties te combineren ontstaat een gedetailleerd en volledig beeld van hoe de buitenruimte van Cartesius wordt gebruikt, welke routes het meest worden belopen en op welke momenten de drukte het grootst is. Dit biedt een waardevolle aanvulling op de handmatige SOPARC-observaties en maakt het mogelijk om ook buiten de vaste meetmomenten data te verzamelen.

9.4 Overdracht aan een volgend groep
Dit prototype is een eerste stap. Voor een volgend groepje of een volgende onderzoeker dat verder wil bouwen op dit werk, is onderstaande overdracht bedoeld als startpunt.

Wat er al is: een werkend lasersysteem dat voetgangers, fietsers en auto's onderscheidt, data opslaat op een SD-kaart met tijdstempel, een 3D-geprinte behuizing op een verstelbare prikker, een gedocumenteerde Arduino-code (V3) die voldoet aan de C-coding richtlijnen en een eerste PCB-ontwerp in Bijlage G.

Wat er nog gedaan moet worden: een waterdichte behuizing ontwerpen van een weerbestendig materiaal zoals ASA of PETG in plaats van PLA, de prikker vervangen door een metalen variant of een wandbevestiging, het PCB-ontwerp laten produceren en testen, het classificatiealgoritme verbeteren voor betere fietserdetectie en het systeem testen bij direct zonlicht en regen om de
betrouwbaarheid in alle weersomstandigheden te bevestigen.

Wat bruikbaar is als referentie: de systeemeisen in Tabel 18, de testresultaten in Tabel 24 en 25 en het KiCad-schema en de V3-code in Bijlage E vormen samen een gedocumenteerde basis waarop direct verder gebouwd kan worden.
]

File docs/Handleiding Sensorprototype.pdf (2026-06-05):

## Handleiding Sensorprototype

Thijs Buisman 1855662 HU

Over dit document
Deze handleiding legt stap voor stap uit hoe je de passantensensor kunt plaatsen, inschakelen, gebruiken en uitlezen. De sensor is bedoeld om automatisch bij te houden hoeveel mensen, fietsers en auto's er door een doorgang in de wijk Cartesius lopen of rijden.

Je hoeft geen technische kennis te hebben om de sensor te gebruiken. Volg gewoon de stappen in deze handleiding en je bent klaar.

💡Lees deze handleiding eerst helemaal door voordat je begint. Dat voorkomt fouten en bespaart tijd.

1. Wat zit er in de set?
Controleer voor je begint of je alle onderdelen hebt. In Tabel 1 en Figuur 1 staat een overzicht.

Tabel 1

Overzicht onderdelen
Onderdeel | Wat is het? | Aantal
Zender (groene behuizing) | Stuurt de laserstraal de doorgang in | 1 stuks
Ontvanger (groene behuizing) | Vangt de laserstraal op en slaat de data op | 1 stuks
Powerbank | Voeding voor de zender en ontvanger | 2 stuks
SD-kaart | Zit al in de ontvanger, slaat de meetdata op | 1 stuks
USB-kabel | Voor het opladen van de powerbanks | 2 stuks

Figuur 1

Overzicht van alle onderdelen

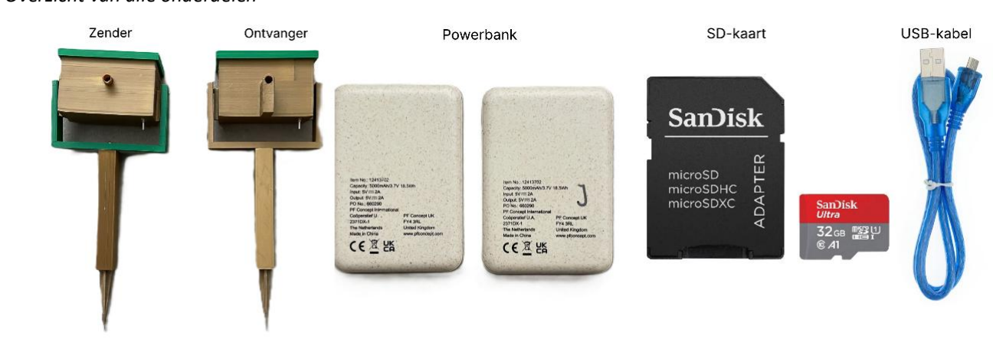
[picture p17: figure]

2. De sensor plaatsen
De sensor bestaat uit twee delen die tegenover elkaar geplaatst worden aan weerszijden van een doorgang. De zender stuurt een laserstraal naar de ontvanger. Wanneer iemand door de doorgang loopt, onderbreekt die persoon de straal en registreert de sensor een passage. Zie Figuur 2 voor de sensor opstelling.

Figuur 2

Opstelling zender en ontvanger tegenover elkaar

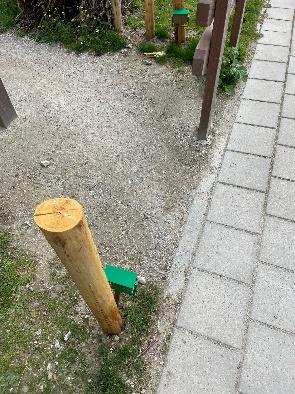
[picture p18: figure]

Stap 1 – Kies de juiste plek
Let bij het kiezen van een locatie op het volgende:
- De doorgang is smal genoeg zodat iedereen langs de sensor loopt (maximaal 2 meter breed).
- Er is geen direct zonlicht dat recht op de voorkant van de ontvanger schijnt.
- De grond is zacht genoeg om de prikker in te steken.

### ⚠ Zorg dat de sensor niet in de weg staat en dat voetgangers er niet over kunnen

struikelen.

Stap 2 – Steek de prikker in de grond
1. Houd de onderkant van de behuizing vast en duw de prikker recht omlaag de grond in.
2. Druk hem net zo ver in tot de behuizing stabiel staat en niet meer wiebelt.
3. Doe hetzelfde met de andere module aan de andere kant van de doorgang.

💡 Is de grond erg hard? Maak dan eerst een klein gaatje met een schroevendraaier of een ander smal voorwerp. Het plastic van de prikker is niet bedoeld voor keiharde ondergronden.

Stap 3 – Zender en ontvanger op gelijke hoogte zetten
4. Controleer of de zender en de ontvanger op exact dezelfde hoogte staan.
5. De opening van de ontvanger (het kleine gaatje aan de voorkant) moet recht gericht zijn op de laserbron van de zender.
6. Stel de sensorhouder bij door de behuizing te kantelen totdat zender en ontvanger recht op elkaar gericht zijn.

💡 Houd je hand voor de ontvanger. Wanneer de laser goed gericht is, schijnt er een rode stip op je hand.

3. De sensor inschakelen
Beide modules hebben een eigen powerbank en een eigen schakelaar aan de onderkant van de behuizing.
7. Controleer of de powerbank voldoende opgeladen is. Druk kort op de knop van de powerbank. Branden er lampjes? Dan is er nog stroom.
8. Schuif de schakelaar aan de onderkant van de zender naar de aan-positie zie Figuur 3.
9. Schuif de schakelaar aan de onderkant van de ontvanger naar de aan-positie zie Figuur 3.
10. De sensor start nu automatisch op. Er hoeft verder niets te worden ingesteld.

⚠ Zet altijd eerst de zender aan en dan de ontvanger. Zo zorgt de software voor een schone start.

💡Zodra de sensor actief is, maakt die automatisch een nieuw bestand aan op de SD-kaart met de huidige datum en tijd als bestandsnaam. Je hoeft niets in te stellen.

Figuur 3

Schakelaar aan de onderkant van de behuizing 1(aan) 0(uit)

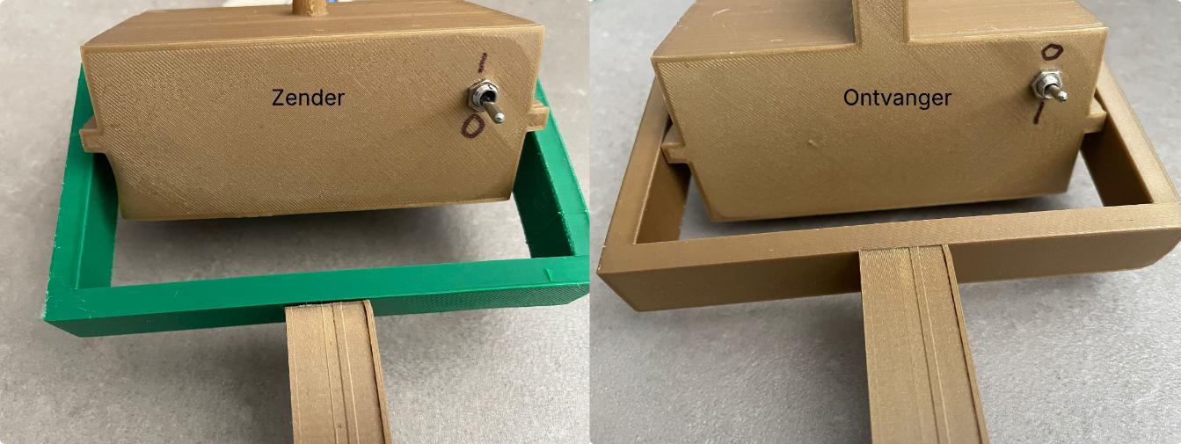
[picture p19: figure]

4. Tijdens de meting
De sensor werkt volledig zelfstandig. Je hoeft niets te doen terwijl de sensor aan staat. Elke keer dat iemand de laserstraal onderbreekt, wordt automatisch geregistreerd of het een voetganger, fietser of auto is.
- Je kunt de sensor gewoon laten staan en later terugkomen.
- De powerbank gaat bij normaal gebruik circa 40 uur mee.
- De sensor is bestand tegen bewolkt weer, maar niet tegen regen. Gebruik de sensor niet bij nat weer.

⚠ Gebruik de sensor niet bij regen of zware wind. De behuizing is niet waterdicht en kan bij harde wind omvallen.

5. De sensor uitzetten en data uitlezen

Uitzetten
11. Schuif de schakelaar van de ontvanger naar de uit-positie.
12. Schuif de schakelaar van de zender naar de uit-positie.

SD-kaart uitlezen
13. Open de deksel aan de bovenkant van de ontvanger.
14. Trek de SD-kaart voorzichtig naar omhoog totdat helemaal eruit is zie Figuur 4.
15. Steek de SD-kaart in je laptop of gebruik een SD-kaartlezer.
16. Open het bestand met de naam die bestaat uit datum en tijd, bijvoorbeeld: 21052026_1445.CSV
17. Open het bestand in Excel. Kies bij het importeren puntkomma (;) als scheidingsteken. 💡Het bestand opent soms als één lange kolom. Selecteer dan de kolom, ga naar 'Gegevens' en kies 'Tekst naar kolommen'. Stel het scheidingsteken in op puntkomma.

Figuur 4

SD-kaart lezer de ontvanger

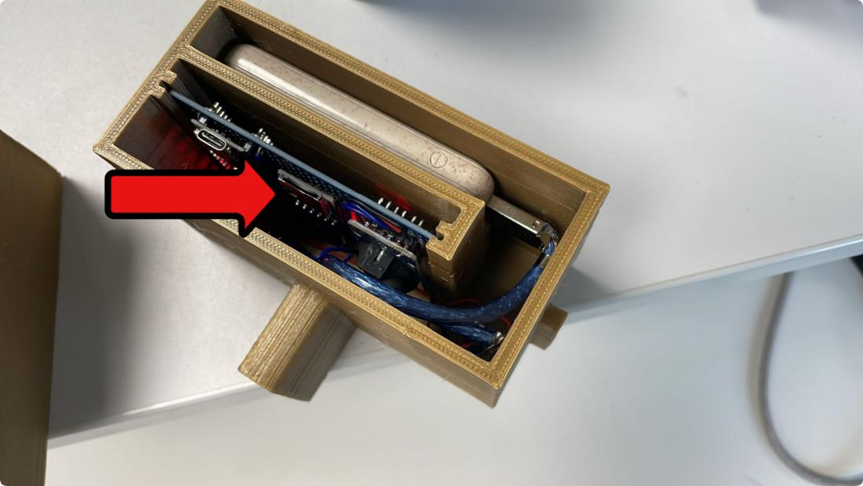
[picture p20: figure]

Wat staat er in het bestand?
Het CSV-bestand bevat vier kolommen zoals te zien is in Tabel 2.

Tabel 2

Uitleg kolommen CSV-bestand
Kolomnaam | Voorbeeld | Betekenis
SensorID | 0x001b | Het unieke nummer van de sensor.
Datum | 2026-05-21 | De datum van de meting.
Tijd | 14:32:05 | Het exacte tijdstip van de passage.
GedetecteerdObject | Voetganger | Wat de sensor heeft geregistreerd: Voetganger, Fietser of Auto.
6. Onderhoud
De sensor heeft weinig onderhoud nodig. Controleer bij elke meetronde het volgende:
- Staat de sensor nog stevig? Controleer of de prikker nog goed in de grond zit, vooral na harde wind.
- Is de voorkant van de ontvanger schoon? Verwijder eventueel vuil of bladeren met een droge doek.
- Is de powerbank nog voldoende opgeladen? Laad hem na elke meetdag op via de meegeleverde USB-kabel.
- Zit de deksel van de ontvanger goed dicht? Zo blijft de elektronica droog en veilig.

De powerbank opladen:
18. Haal de powerbank uit de behuizing via de opening aan de onderkant.
19. Sluit de USB-kabel aan op de powerbank en op een stopcontact of laptop.
20. De powerbank is volledig opgeladen als alle lampjes branden. Dit duurt gemiddeld 4 tot 5 uur.
21. Plaats de powerbank terug in de behuizing.
7. Problemen oplossen
Werkt de sensor niet zoals verwacht? Kijk dan eerst in Tabel 3 of je probleem erin staat.

Tabel 3

Veelvoorkomende problemen en oplossingen
Probleem | Mogelijke oorzaak | Oplossing
De sensor start niet op | Powerbank is leeg of uitgeschakeld | Controleer of de schakelaar aan staat en druk op de knop van de powerbank om te kijken of die nog stroom heeft.
De sensor registreert niets | De laser en fotodiode staan niet goed op elkaar gericht | Controleer of de laser en de ontvanger recht tegenover elkaar staan op gelijke hoogte. Stel de sensorhouder opnieuw in.
Er staat niets op de SD-kaart | De SD-kaart zit niet goed of er zijn nog geen passages geregistreerd | Controleer of de SD-kaart goed in de gleuf zit. Wacht totdat iemand langs loopt en kijk dan of er een bestand is aangemaakt.
De sensor registreert van alles maar de aantallen kloppen niet | Zonlicht of ruis verstoort de meting | Zorg dat de ontvanger in de schaduw staat of gebruik het meegeleverde kokertje voor de fotodiode.
Het CSV-bestand opent niet goed in Excel | Excel herkent de puntkomma niet als scheidingsteken | Open Excel, kies 'Gegevens importeren' en stel het scheidingsteken in op puntkomma (;).

Staat je probleem er niet bij? Neem dan contact op met de onderzoeker van Groep 8 QUEST(2026 CD) via de Hogeschool Utrecht.

8. Veiligheid en privacyregels
⚠ Kijk nooit rechtstreeks in de laserstraal van de zender. Hoewel de laser zwak is, kan direct oogcontact irritatie veroorzaken.

Privacy:
De sensor maakt geen foto's en slaat geen persoonlijke gegevens op. Het systeem registreert alleen het tijdstip en het type passant (voetganger, fietser of auto). Er worden geen beelden gemaakt. Het systeem voldoet aan de AVG-wetgeving.

Vandalisme:
Zijn er tekenen van vandalisme of is de sensor beschadigd? Verwijder de sensor dan direct en meld dit bij de onderzoeker.
9. Contact
Heb je vragen over de sensor of werkt er iets niet? Neem dan contact op:
- Groep 8 – QUEST(2026 CD), Hogeschool Utrecht
- Begeleider: Marit Béguin, Hogeschool Utrecht
- Opdrachtgever: Hanneke Kruize, Lectoraat Building Future Cities

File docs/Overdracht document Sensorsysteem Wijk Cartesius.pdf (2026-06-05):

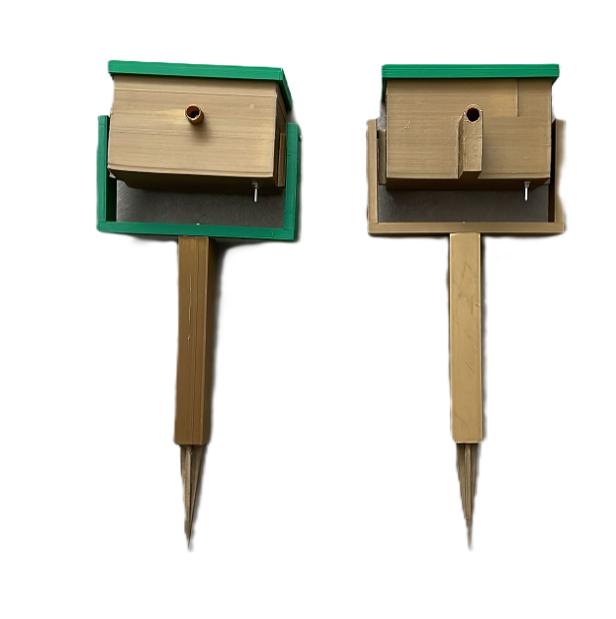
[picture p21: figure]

Overdracht document Sensorsysteem Wijk Cartesius | 1 van 56

# Overdracht document

Sensorsysteem Wijk Cartesius, Utrecht

Auteur | Thijs Buisman · Studentnummer 1855662
Opleiding | GCL/IDE · QUEST 30EC · Klas TDFE-EV6QUEST-25
Instelling | Hogeschool Utrecht
Project | Gezond leven in Cartesius (Lectoraat Building Future Cities)
Groep | Groep 8 (Boas Janssen, Joost, Kim, Melisa, Stef, Thijs Buisman)
Opdrachtgever | Hanneke Kruize · Lectoraat Building Future Cities (RAAK PRO)
Docentcoach | Marit Béguin
Datum document | 5 Juni 2026
Versie | V1.0

Het bestuur van de Stichting Hogeschool Utrecht te Utrecht aanvaardt geen enkele aansprakelijkheid voor schade voortvloeiende uit het gebruik van enig gegeven, hulpmiddel, werkwijze of procedure in dit verslag beschreven. Vermenigvuldiging zonder toestemming van de auteur(s), de school of het bedrijf (indien van toepassing) is niet toegestaan.

Overdracht document Sensorsysteem Wijk Cartesius | 2 van 56

# Inhoudsopgave

Overdracht document Sensorsysteem Wijk Cartesius | 3 van 56

# 1 Inleiding

Dit document is bedoeld als formele overdracht van het sensorsysteem dat is ontwikkeld in het kader van het QUEST-project 'Gezond leven in Cartesius'. Het richt zich op iedereen die verder wil bouwen op dit werk: een volgend onderzoeksteam, een student of een externe partij die het systeem wil doorontwikkelen of opschalen.

Het document beschrijft op heldere wijze wat er al is gedaan, waar het project nu staat en welke concrete stappen er nog nodig zijn. Daarnaast staat beschreven waar alle bestanden te vinden zijn, zodat het werk zo eenvoudig mogelijk overgenomen kan worden.

De drie technische bijlagen die bij dit document horen bevatten de volledige onderbouwing: de Proof of Concept (PoC) met testresultaten, het PCB-ontwerp en de gebruikershandleiding.

Overdracht document Sensorsysteem Wijk Cartesius | 4 van 56

# 2 Projectachtergrond

Het project 'Gezond leven in Cartesius' onderzoekt hoe de inrichting van de buitenruimte in de wijk Cartesius in Utrecht het gezonde gedrag van bewoners beïnvloedt, met beweging en sociale interactie als kernthema's. De wijk heeft een Blue Zone-ambitie: een woonomgeving die uitnodigt tot bewegen en ontmoeten.

Om objectieve data te verzamelen over het gebruik van de buitenruimte is een automatisch passantentelsysteem ontwikkeld. De handmatige observatiemethode SOPARC is namelijk arbeidsintensief en beperkt tot momentopnames. Een sensorsysteem dat continu en automatisch meet, biedt aanvullende en bredere data.

Na vergelijking van meerdere technieken (camera, PIR-sensor, ultrasone sensor) is gekozen voor een lasersensor met fotodiode. Dit systeem is nauwkeurig, kostenefficiënt en volledig AVG-proof: er worden geen beelden gemaakt en geen persoonsgegevens opgeslagen.

Overdracht document Sensorsysteem Wijk Cartesius | 5 van 56

# 3 Wat er is gemaakt

Hieronder staat een overzicht van alle onderdelen die zijn ontwikkeld en opgeleverd.

## 3.1 Prototype (Arduino Nano)

Het eerste werkende prototype is opgebouwd rondom een Arduino Nano en bestaat uit de volgende onderdelen:
- Een fotodiode (SGPD5051C6) op analoge pin A3 met een 10 kΩ pull-down weerstand, uitgelezen via een instelbare drempelwaarde (LASER_THRESHOLD).
- Een RTC-module DS3231 op de I2C-bus (SDA=A4, SCL=A5) voor nauwkeurige tijdregistratie, inclusief een knoopcel als back-up bij stroomuitval.
- Een SD-kaartmodule op de SPI-bus (MOSI=D11, MISO=D12, SCK=D13, CS=D4) die de data wegschrijft als CSV-bestand met automatische bestandsnaam op basis van datum en tijd.
- Een lasermodule KY-008 als zender, los aangestuurd via een 5V powerbank + switch.

## 3.2 Sensorcode (V1 t/m V3)

De Arduino-code is in drie versies ontwikkeld:
- V1 – Eerste werkende integratie: digitalRead op D2, vaste bestandsnaam (LOG.CSV), basisclassificatie op drie patronen.
- V2 – Verbeteringen: analogRead op A3 met drempelwaarde, rausfiltering (MIN_BREAK_DURATION = 20 ms), dynamische bestandsnaam op basis van datum en tijd.
- V3 – Definitieve versie: volledig herschreven volgens de C-coding richtlijnen van de opleiding. Modulaire opbouw met functieprototypes, documentatieblokken per functie en duidelijke scheiding van logica. Dit is de versie die in productie is gebruikt voor de veldtest.

De klassificatielogica in V3 werkt als volgt:
- Auto: maximale onderbrekingsduur > 800 ms.
- Fietser: 3 of meer afzonderlijke onderbrekingen (spaken van het wiel).
- Voetganger: alle overige gevallen.

## 3.3 3D-geprinte behuizing

De behuizing is modulair ontworpen en bestaat uit zeven onderdelen, geprint in PLA op een Ender V3 SE:
- Onderdeel 1 – De prikker (2x): voor stabiele plaatsing in de grond.
- Onderdeel 2 – Het tussenstuk (2x): zorgt voor de juiste hoogte voor autodetectie. Aangepast van cilindrisch naar vierkant na printproblemen.
- Onderdeel 3 – De sensorhouder (2x): verbindt het tussenstuk met de behuizing; kantelbaar voor nauwkeurige uitlijning. Wanddikte vergroot na eerste test.
- Onderdelen 4a/5a – Behuizing en deksel ontvanger (1x elk): ruimte voor powerbank, protoboard en bedrading; inclusief kokertje voor de fotodiode om zonlichtinval te reduceren.
- Onderdelen 4b/5b – Behuizing en deksel zender (1x elk): compacter dan de ontvanger; ruimte voor lasermodule, powerbank en schakelaar.

Totaal materiaalgebruik: 573 gram PLA, totale printtijd circa 49 uur.

Overdracht document Sensorsysteem Wijk Cartesius | 6 van 56

## 3.4 Veldtest (21 mei 2026)

Het prototype is gedurende vier uur getest in de buitenruimte van Cartesius bij de doorgang van deelgebied 2, tussen 14:45 en 18:45, bij bewolkt en droog weer. Tegelijkertijd is handmatig geregistreerd via de SOPARC-webapp. De resultaten zijn als volgt:

Gebruikerstype | Sensor | Handmatig | Verschil | Afwijking
Voetganger | 50 | 47 | +3 | 6,4%
Fietser | 28 | 32 | –4 | 12,5%
Auto | 3 | 0 | +3 | –
Totaal | 81 | 79 | +2 | 2,5%

De totale foutmarge van 2,5% valt ruim binnen de gestelde eis van maximaal 15%. Alle must have systeemeisen zijn behaald.

## 3.5 PCB-ontwerp V1 (KiCad 9.0)

Op basis van het werkende prototype is een eerste PCB-ontwerp gemaakt in KiCad 9.0. Er zijn twee aparte printplaten ontworpen:
- PCB_sensor (ontvanger): tweelaags SMD-printplaat met STM32L010K8Tx-microcontroller, DS3231M RTC, SD-kaartlezer, fotodiode SGPD5051C6, USB-C oplaadcircuit (TP4056), automatische stroomkiezer (TPS2115A) en 3,3 V LDO-regelaar (MIC5365). De analoge fotodiode-lijn is fysiek gescheiden van de digitale SPI-lijnen.
- PCB_laser (zender): compacte tweelaags SMD-printplaat met laserdiode, stroombegrenzende weerstand (R1), identiek voedingscircuit als de sensorprint, en een schuifschakelaar voor aan/uit.

Beide printplaten zijn elektrisch gevalideerd in KiCad (ERC/DRC geslaagd). Ze zijn nog niet gefabriceerd of getest als hardware. Fiducial markers ontbreken nog; die zijn nodig voor automatische pick-and-place productie.

## 3.6 Gebruikershandleiding

Er is een complete gebruikershandleiding opgesteld die beschrijft hoe de sensor geplaatst, ingeschakeld, gebruikt en uitgelezen wordt. De handleiding is geschreven voor niet-technische gebruikers en bevat een probleemoplossingtabel, veiligheids- en privacyinformatie.

Overdracht document Sensorsysteem Wijk Cartesius | 7 van 56

# 4 Huidige status

Onderstaande tabel geeft in één oogopslag de status van alle onderdelen van het project.
Onderdeel | Versie | Status
Werkend prototype (Arduino Nano) | V1 (protoboard) | ✓ Gereed
Sensorcode | V3 | ✓ Gereed
3D-geprinte behuizing | Definitief | ✓ Gereed
Veldtest & validatie | 21 mei 2026 | ✓ Gereed
Gebruikershandleiding | V1 | ✓ Gereed
PCB-ontwerp (KiCad schema + layout) | V1 | ⚠ Gedeeltelijk
PCB-fabricage en hardwaretest | – | ✗ Niet gestart
Waterdichte behuizing (ASA/PETG, IP65) | – | ✗ Niet gestart
Verbeterd classificatiealgoritme | – | ✗ Niet gestart
Meerdere sensoren op schaal (16 locaties) | – | ✗ Niet gestart
Legenda:
- ✓ Gereed – volledig afgerond en getest.
- ⚠ Gedeeltelijk – ontwerp gereed, maar nog niet gefabriceerd of gevalideerd als hardware.
- ✗ Niet gestart – gedefinieerd als vervolgstap; zie Hoofdstuk 6.

Overdracht document Sensorsysteem Wijk Cartesius | 8 van 56

# 5 Bekende beperkingen

Tijdens de ontwikkeling en de veldtest zijn een aantal beperkingen vastgesteld die relevant zijn voor een volgend team:
- Fietserdetectie zit met 12,5% afwijking dicht tegen de grenswaarde van 15% aan. Fietsen met weinig of dichte spaken genereren te weinig onderbrekingen, waardoor ze als voetganger worden geclassificeerd.
- Drie passages zijn fout als 'auto' geclassificeerd doordat een persoon of fietser de laserstraal langdurig blokkeerde. Het algoritme kijkt uitsluitend naar de duur van de onderbreking.
- De behuizing is niet waterdicht en is daardoor niet geschikt voor gebruik bij regen. De prikker van PLA werkt niet goed op harde ondergrond.
- De maximale detectieafstand is circa 2 meter; bij grotere afstand spreidt de laserbundel te veel uit.
- Het systeem kan geen meerdere passanten naast elkaar detecteren (leidt tot ondertelling bij drukte).
- Dieren kunnen de laserstraal onderbreken en worden dan als passant geregistreerd.
- Het PCB-ontwerp is nog niet gefabriceerd of getest; het is uitsluitend elektrisch gevalideerd in KiCad.
- Betrouwbaarheid bij direct zonlicht is gedeeltelijk opgelost via de drempelwaarde en het kokertje, maar nog niet getest bij extreme omstandigheden.

Overdracht document Sensorsysteem Wijk Cartesius | 9 van 56

# 6 Vervolgstappen

Op basis van de testresultaten en de bekende beperkingen zijn de volgende vervolgstappen aanbevolen. Ze zijn ingedeeld op prioriteit.

## 6.1 Hoge prioriteit: direct uitvoerbaar

1. Het PCB-ontwerp (V1) laten fabriceren bij een goedkope PCB-fabrikant (bijv. JLCPCB of PCBWay) en de printplaten functioneel testen. Het KiCad-projectbestand staat in de bestandenmap (zie Hoofdstuk 7). Voeg voor productie nog fiducial markers toe aan beide prints.
2. Het classificatiealgoritme verbeteren voor betere fietserdetectie. Oplossingsrichting: een tweede sensormodule parallel plaatsen om de breedte van een object te meten, zodat meerdere gebruikers naast elkaar te onderscheiden zijn.
3. De sensorcode testen bij direct zonlicht en regen. Stel de LASER_THRESHOLD in Sensor_code_V3.ino opnieuw in op basis van de gemeten waarden in die omstandigheden.

## 6.2 Middellange termijn: behuizing en mechaniek

4. Een waterdichte behuizing ontwerpen in ASA of PETG (minimaal IP65-certificering). Alle openingen (schakelaar, lensopening) afdichten met rubberringen of een transparante afdekking.
5. De prikker vervangen door een metalen variant of het systeem bevestigen aan een bestaand hekwerk, paal of lantaarnpaal. Dit maakt plaatsing sneller en stabieler.
6. Een verstelbaar scharniermechanisme met vergrendeling toevoegen aan de sensorhouder, aangevuld met een indicatie-LED of buzzer die aangeeft wanneer de laser de fotodiode correct raakt.

## 6.3 Opschaling: meerdere sensoren

Als bovenstaande verbeteringen zijn doorgevoerd, is het systeem klaar voor bredere inzet. In de PoC-bijlage (Bijlage A) zijn 16 aanbevolen meetlocaties in Cartesius beschreven, ingedeeld in vier categorieën:
- Rood - hoofdingangen (locaties 1 en 2): hoogste prioriteit, alle in- en uitstroom passeert hier.
- Blauw - parkeerlocaties (locaties 3, 4, 15, 16): voor analyse van autogebruik.
- Groen - moestuin en picknickzone (locaties 5 t/m 8): gebruik recreatieve buitenruimte.
- Geel - binnenhof deelgebied 2 (locaties 9 t/m 14): volledig beeld van het binnengebied.

Met twee sensoren op de hoofdingangen (locaties 1 en 2) is al een volledig beeld van de totale in- en uitstroom van de wijk te verkrijgen. Dit is de meest kostenefficiënte eerste stap voor opschaling.

Overdracht document Sensorsysteem Wijk Cartesius | 10 van 56

# 7 Toegang tot bestanden

Alle bestanden die nodig zijn om verder te bouwen op dit project zijn beschikbaar via de GitHub-repository van dit project.

## 7.1 GitHub repository

De bestanden staan op de volgende pagina: https://github.com/Thijs-Buisman/sensorsysteem-cartesius Zo open je de repository:
1. Klik op de link hierboven, of kopieer hem in je browser.
2. Je ziet nu een overzicht van alle mappen en bestanden.
3. Klik op een map om hem te openen en klik op een bestand om de inhoud te bekijken.
4. Wil je een bestand downloaden? Klik erop en kies dan "Download raw file" (het download-icoontje rechtsboven in het bestand).
5. Wil je alles in één keer downloaden? Klik op de groene knop "Code" → "Download ZIP". Dan download je alle bestanden tegelijk als ZIP-bestand.

## 7.2 Bestandsformaten en tools

Voor het werken met de bestanden zijn de volgende tools nodig:
- Arduino IDE (gratis, arduino.cc) – voor het bekijken en uploaden van de .ino sensorcode.
- KiCad 9.0 (gratis, kicad.org) – voor het bekijken en bewerken van de PCB-schema's en -layouts.
- Autodesk Inventor – voor het bewerken van de originele 3D-ontwerpbestanden (.ipt).
- PrusaSlicer of Ultimaker Cura (gratis) – voor het slicen van de STL-bestanden voor 3D-printen.
- Microsoft Excel of LibreOffice Calc – voor het openen van de CSV-testdata en het validatiebestand.

Overdracht document Sensorsysteem Wijk Cartesius | 11 van 56

# 8 Contactgegevens

Heb je vragen over dit project of wil je meer toelichting? Neem dan contact op via de Hogeschool Utrecht:
Naam | Thijs Buisman
Studentnummer | 1855662
Klas | TDFE-EV6QUEST-25 · Groep 8
Instelling | Hogeschool Utrecht – GCL/IDE
Docentcoach | Marit Béguin (HU)
Opdrachtgever | Hanneke Kruize – Lectoraat Building Future Cities

Overdracht document Sensorsysteem Wijk Cartesius | 12 van 56

# Afkortingen en begrippen

## Lijst van Illustraties

## Figuren

Figuur 1 - Schematische weergave van de werking van de laser-fietsteller (Bron: nano banana 2) | 16
Figuur 2 – Test sensor schakling op breabord | 19
Figuur 3 - Schema sensor prototype in KiCad | 19
Figuur 4 - Sensor schakling op protoboard | 20
Figuur 5 - Overzicht van alle onderdelen van de behuizing | 21
Figuur 6 - De prikker | 21
Figuur 7 - Het tussenstuk | 22
Figuur 8 - De sensorhouder | 22
Figuur 9 - Behuizing ontvanger | 23
Figuur 10 - Behuizing zender | 23
Figuur 11 - Definitieve onderdelen na ontwerpiteraties | 24
Figuur 12 - Complete opstelling zender en ontvanger | 25
Figuur 13 - Flowchart sensor code v2 | 27
Figuur 14 - Testopstelling: locatie (links), sensoropstelling op locatie (midden) en SOPARC-webapp voor
validatie (rechts) | 35
Figuur 15 - Screenshot van de samengevoegde sensor- en webapp-data in Excel | 35
Figuur 16 - Aanbevolen sensorlocaties in Cartesius, gekleurd per categorie | 39
Figuur 17 - Volledige schema ontvanger | 42
Figuur 18 - Schema sensor, klok en SD-kaart | 43
Figuur 19 - Schema voeding | 44
Figuur 20 - Schema microcontroller en connectoren | 45
Figuur 21 - Volledige schema zender | 47
Figuur 22 - De twee lagen van de sensorprintplaat (F.Cu en B.Cu) | 49
Figuur 23 - De twee lagen van de laserprintplaat (F.Cu en B.Cu) | 49
Figuur 24– 3D weergave sensorprintplaat | 51
Figuur 25 - 3D weergave laserprintplaat | 51
Figuur 26 - Overzicht van alle onderdelen | 52
Figuur 27 - Opstelling zender en ontvanger tegenover elkaar | 52
Figuur 28 - Schakelaar aan de onderkant van de behuizing 1(aan) 0(uit) | 53
Figuur 29 - SD-kaart lezer de ontvanger | 54

## Tabellen

Tabel 1 – Eisenlijst sensorsysteem | 17
Tabel 2 - Kostenoverzicht ontwikkeling prototype | 18
Tabel 3 - Printoverzicht behuizing | 24
Tabel 4 – Functies code | 28
Tabel 5 - Sensordata: geregistreerde passages | 36
Tabel 6 - Handmatige telling via webapp: geregistreerde passages | 36
Tabel 7 - Vergelijking sensor vs. handmatige telling | 36
Tabel 8 - Toetsing systeemeisen | 37
Tabel 9 - Checklist Schema Sensor | 46
Tabel 10 - Checklist Schema Laser | 48

Overdracht document Sensorsysteem Wijk Cartesius | 13 van 56

## Gebruikte afkortingen en symbolen

Afkorting / Symbool | Betekenis
PoC | Proof of Concept
RTC | Real-Time Clock
SD | Secure Digital (geheugenkaart)
CSV | Comma-Separated Values (bestandsformaat)
PCB | Printed Circuit Board (printplaat)
SMD | Surface-Mounted Device
SPI | Serial Peripheral Interface
I2C | Inter-Integrated Circuit
USB-C | Universal Serial Bus Type-C
LDO | Low Drop-Out (spanningsregelaar)
IP65 | Mate van water- en stofdichtheid
PLA | Polylactic Acid (3D-printmateriaal)
ASA | Acrylonitrile Styrene Acrylate (3D-printmateriaal)
PETG | Polyethylene Terephthalate Glycol
AVG | Algemene Verordening Gegevensbescherming
SOPARC | System for Observing Play and Recreation in Communities
ms | milliseconde
V | Volt
kΩ | kilo-ohm
✓ | Gereed
⚠ | Gedeeltelijk gereed
✗ | Niet gestart

## Verklarende woordenlijst

Term | Uitleg
Sensorsysteem | Systeem dat automatisch passanten detecteert en registreert
Fotodiode | Sensor die licht omzet in een elektrisch signaal
Lasersensor | Meetopstelling met laser en ontvanger voor detectie
Arduino Nano | Microcontroller gebruikt voor het prototype
Drempelwaarde (threshold) | Waarde waarbij een signaal als detectie wordt gezien
Classificatielogica | Algoritme dat bepaalt of iets een voetganger, fietser of auto is
Onderbreking | Moment waarop de laserstraal wordt geblokkeerd
Veldtest | Praktijktest in de echte omgeving
Behuizing | Fysieke omkasting van het systeem
Prototype | Eerste werkend model van het systeem
Validatie | Controleren of het systeem correct werkt

Overdracht document Sensorsysteem Wijk Cartesius | 14 van 56
Detectieafstand | Maximale afstand waarop de sensor werkt
Pull-down weerstand | Weerstand die een ingang naar laag (0V) trekt
Modulaire opbouw | Opbouw uit losse, vervangbare onderdelen
Powerbank | Draagbare batterij voor voeding
PCB-ontwerp | Ontwerp van een printplaat voor definitieve hardware
Pick-and-place | Geautomatiseerd plaatsen van componenten op PCB
Fiducial markers | Referentiepunten voor productie van PCB’s
Opschaling | Uitbreiden naar meerdere sensoren/locaties
Meetlocatie | Plaats waar data wordt verzameld

Overdracht document Sensorsysteem Wijk Cartesius | 15 van 56

# Bijlagen

De volgende drie documenten zijn als bijlage bij dit overdrachts document gevoegd. Ze bevatten de volledige technische onderbouwing.
Nr. | Document | Inhoud (samenvatting)
Bijlage A | Proof of Concept Sensorsysteem (Proof_of_Concept_Sensorsysteem.pdf) | Volledige technische verantwoording: keuze voor lasersysteem, systeemeisen (MoSCoW), componentkeuze, circuit, behuizing, code (V1–V3), veldtest en aanbevelingen.
Bijlage B | PCB-ontwerp sensor V1 (PCB-ontwerp_sensor_V1.pdf) | Gedetailleerde uitleg van de KiCad-schema's en PCB-layouts van de sensor- en laserprintplaat, inclusief checklists en 3D-weergaves.
Bijlage C | Handleiding Sensorprototype (Handleiding_Sensorprototype.pdf) | Stap-voor-stap gebruiksaanwijzing voor plaatsing, gebruik, uitlezen en onderhoud van het prototype. Inclusief probleemoplossingtabel.

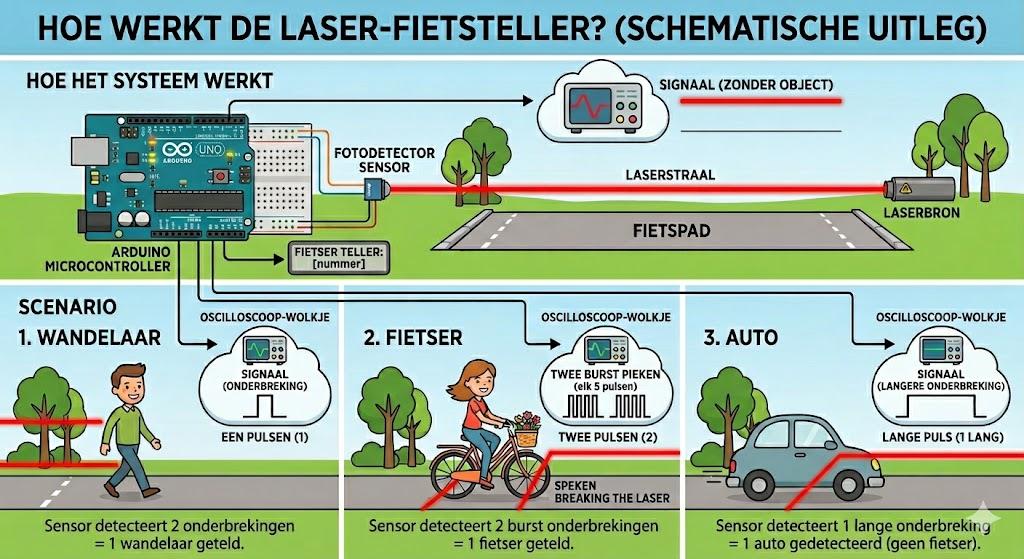
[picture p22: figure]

Overdracht document Sensorsysteem Wijk Cartesius | 16 van 56

## Bijlage A: Proof of Concept: Sensorsysteem

## 1. Aanleiding en keuze voor de lasersensor

Binnen het onderzoek naar het gebruik van de buitenruimte in de wijk Cartesius was er behoefte aan een methode om passanten continu en objectief te tellen. De handmatige observatiemethode SOPARC levert waardevolle data op, maar is arbeidsintensief en beperkt tot momentopnames. Daarom is onderzocht of sensortechnologie dit proces kon automatiseren.

Bij de keuze voor een geschikte meettechniek zijn meerdere alternatieven overwogen:
- Camera met computer vision: betrouwbaar en nauwkeurig, maar maakt beeldopnames van mensen. Dit stuit op privacybezwaren en is niet AVG-proof voor gebruik in de openbare ruimte.
- PIR-sensor (bewegingssensor): goedkoop en eenvoudig, maar te ongericht. Reageert op warmte en beweging zonder onderscheid te maken tussen verschillende gebruikerstypen.
- Ultrasone sensor (HC-SR04): geschikt voor afstandsmeting, maar minder betrouwbaar bij smalle doorgangen met meerdere passanten tegelijk.
- Lasersensor met fotodiode: nauwkeurig, AVG-proof (geen beeldopname), kostenefficiënt en geschikt voor het detecteren van patronen per gebruikerstype.

De keuze is gevallen op het lasersysteem. Dit systeem werkt volledig anoniem er worden geen beelden gemaakt en geen persoonsgegevens opgeslagen wat aansluit bij de privacy-eisen die gelden voor onderzoek in een woonwijk.

De werking van het systeem is schematisch weergegeven in Figuur 1. Hierin is te zien hoe de laserstraal tussen de laserbron en de fotodetector loopt, en hoe verschillende gebruikerstypen (wandelaar, fietser en auto) elk een herkenbaar onderbrekingspatroon veroorzaken.

Figuur 1 - Schematische weergave van de werking van de laser-fietsteller (Bron: nano banana 2)

Overdracht document Sensorsysteem Wijk Cartesius | 17 van 56

## 2. Systeemeisen

Om te kunnen beoordelen of het prototype voldoet aan de gestelde verwachtingen, zijn vooraf systeemeisen opgesteld. Deze eisen zijn geprioriteerd volgens de MoSCoW-methode zo als te zien is in Tabel 1.

MoSCoW | Eis
Must have | Het systeem detecteert een onderbreking van de laserstraal betrouwbaar bij minimaal 2 meter afstand tussen laser en fotodiode.
Must have | Elke detectie wordt opgeslagen met een correcte tijdstempel (datum en tijd) op de SD-kaart.
Must have | Het systeem onderscheidt minimaal drie gebruikerstypen: voetganger, fietser en auto.
Must have | Het systeem werkt minimaal 8 uur aaneengesloten op een powerbank van 5000 mAh.
Should have | Het systeem werkt betrouwbaar bij direct zonlicht zonder valse detecties.
Should have | De foutmarge ten opzichte van handmatige telling bedraagt maximaal 15%.
Should have | Het systeem logt geen dubbeltellingen bij één passage.
Could have | Het systeem detecteert de looprichting van een passant.
Could have | De data wordt automatisch geëxporteerd naar een leesbaar CSV-bestand met kolomkoppen.
Won't have | Draadloze datatransmissie (WiFi/LoRa).
Won't have | Realtime monitoring op afstand.
Won't have | Automatische classificatie via machine learning.

Tabel 1 – Eisenlijst sensorsysteem

Overdracht document Sensorsysteem Wijk Cartesius | 18 van 56

## 3. Componentenkeuze en kostenoverzicht

Op basis van de gekozen meettechniek zijn de benodigde componenten geselecteerd. Daarbij is gelet op beschikbaarheid, prijs en geschiktheid voor buiteninzet. Bewust is gekozen voor een opstelling zonder draadloze verbinding, zodat het systeem volledig zelfstandig functioneert en niet afhankelijk is van een netwerkverbinding. Onderstaande Tabel 2 toont een overzicht van alle onderdelen en de bijbehorende kosten.

Onderdeel | Specificatie | Kosten
Arduino Nano | Microcontroller voor de verwerking | € 9,99
Laser module KY-008 | Laserbron voor de straalonderbreking | € 1,50
Clock module DS3231 | 2 stuks (voor exacte tijdsregistratie) | € 5,40
Mini SD module | SPI interface voor data-opslag | € 2,27
Micro-SD Kaart 32GB | Lokale data-opslag | € 17,99
Photodiode SGPD5051C6 | 5mm flat lens (detectie van de straal) | € 1,85
Weerstand kit | Diverse componenten voor circuit | € 2,50
Kabel rood/zwart | Solid core 0,25 mm (25m) | € 0,79
Solder board | 2 stuks voor montage | € 1,40
3D print filament | 150 gram (voor behuizing) | € 2,25
Powerbank | 2 stuks (5000 mAh) voor voeding | € 37,98
Totaal | | € 83,92

Tabel 2 - Kostenoverzicht ontwikkeling prototype

Opmerking: verzendkosten zijn niet meegenomen omdat een deel van de componenten al in eigen bezit was.


Overdracht document Sensorsysteem Wijk Cartesius | 19 van 56

## 4. Aansluiting en opbouw van het circuit

### 4.1 Test op breadboard

Voordat de componenten definitief werden gesoldeerd, is de volledige schakeling eerst opgebouwd op een breadboard. Dit maakt het eenvoudig om aansluitingen te testen en fouten te corrigeren zonder schade aan de onderdelen. Tijdens de breadboard-fase is gecontroleerd of:
- De fotodiode het lasersignaal correct ontvangt en verwerkt.
- De RTC-module de juiste tijd doorgeeft aan de Arduino.
- De SD-kaartmodule data wegschrijft zonder fouten.
- De Arduino Nano de signalen correct interpreteert en logt.
Tijdens deze fase is ook een belangrijk probleem ontdekt met de aansluiting van de fotodiode. Eerst was de fotodiode aangesloten op digitale pin D2 met een 1MΩ pull-down weerstand naar GND. Binnen werkte dit correct, maar buiten in direct zonlicht zag het systeem continu een laser terwijl die er niet was. De hoge weerstandswaarde maakte de fotodiode te gevoelig voor omgevingslicht. Dit is opgelost door over te stappen op een 10kΩ pull-down weerstand en de fotodiode aan te sluiten op analoge pin A3. Hierdoor kon in de code een drempelwaarde worden ingesteld waarboven een signaal pas als laser wordt gedetecteerd.

De breadboard-opstelling is te zien in Figuur 2.

Figuur 2 – Test sensor schakling op breabord.

### 4.2 Schematisch ontwerp in KiCad

Het aansluitschema is uitgewerkt in KiCad. Dit schema toont hoe de Arduino Nano, de RTC-module (DS3231), de SD-kaartmodule en de fotodiode op elkaar zijn aangesloten. De schematische weergave is te zien in Figuur 3.

Figuur 3 - Schema sensor prototype in KiCad

Belangrijkste aansluitingen:
- Fotodiode → analoge ingang A3 van de Arduino Nano, met een 10kΩ pull-down weerstand naar GND.
- RTC DS3231 → I2C-bus (SDA op A4, SCL op A5).
- SD-kaartmodule → SPI-bus (MOSI op D11, MISO op D12, SCK op D13, CS op D10).


Overdracht document Sensorsysteem Wijk Cartesius | 20 van 56
- Voeding → 5V en GND van de powerbank via USB naar de Arduino, die de overige modules voedt.

### 4.3 Solderen op protoboard

Na goedkeuring van het schema zijn de componenten gesoldeerd op een soldeerbordje (protoboard). Hierbij is gebruikgemaakt van solid core kabel (0,25 mm) voor vaste verbindingen.

Tijdens het solderen deed zich een complicatie voor: twee RTC DS3231-modules bleken defect te zijn na het solderen. Dit heeft ertoe geleid dat de klokmodule twee keer opnieuw gesoldeerd en vervangen moest worden voordat het systeem correct functioneerde. Dit benadrukt het belang van het testen van componenten vóór definitieve montage. Het gesoldeerde protoboard is te zien in Figuur 4

Figuur 4 - Sensor schakling op protoboard.


Overdracht document Sensorsysteem Wijk Cartesius | 21 van 56

## 5. Behuizing

Voor de behuizing van het sensorsysteem is een modulair ontwerp gekozen. Zowel de zender (laser) als de ontvanger (fotodiode met protoboard) bestaan elk uit vijf onderdelen, waarvan drie identiek zijn. Dit betekent dat deze drie onderdelen onderling verwisselbaar zijn, wat het systeem eenvoudiger maakt om te produceren en te onderhouden.

De gedeelde onderdelen zijn de prikker, het tussenstuk en de sensorhouder. De behuizing zelf verschilt per module omdat de ruimte-inwendige eisen anders zijn. Een overzicht van alle onderdelen van de behuizing is te zien in Figuur 5.

Figuur 5 - Overzicht van alle onderdelen van de behuizing

Onderdeel 1 - De prikker
De prikker is een spits toelopend onderdeel dat in de grond wordt gestoken, vergelijkbaar met de pennen van buitenlampen zo als te zien is in Figuur 6. Dit zorgt voor een stabiele en rechte plaatsing in de buitenomgeving zonder dat er geboord of geschroefd hoeft te worden in bestaande constructies.

Figuur 6 - De prikker


Overdracht document Sensorsysteem Wijk Cartesius | 22 van 56

Onderdeel 2 - Het tussenstuk
Het tussenstuk is cilindrisch van vorm en verbindt de prikker met de rest van de opstelling zo als te zien is in Figuur 7. Het zorgt ervoor dat de zender en ontvanger op de juiste hoogte komen te staan om ook auto's betrouwbaar te kunnen detecteren. Aan de onderkant past de prikker in het tussenstuk. Aan de bovenkant zit een gat voor een heat insert, zodat er een schroefdraadverbinding ontstaat waarmee de sensorhouder horizontaal verstelbaar is.

Figuur 7 - Het tussenstuk

Onderdeel 3 - De sensorhouder
De sensorhouder verbindt het tussenstuk met de behuizing van de sensor. Hij heeft drie gaten: twee voor de bevestiging aan het tussenstuk en één om de behuizing van de sensor zelf te kunnen kantelen. Door deze kantelverbinding kunnen zowel de zender als de ontvanger nauwkeurig op elkaar worden gericht, wat essentieel is voor een betrouwbare laserverbinding over langere afstanden. De sensorhouder is te zien in Figuur 8.

Figuur 8 - De sensorhouder

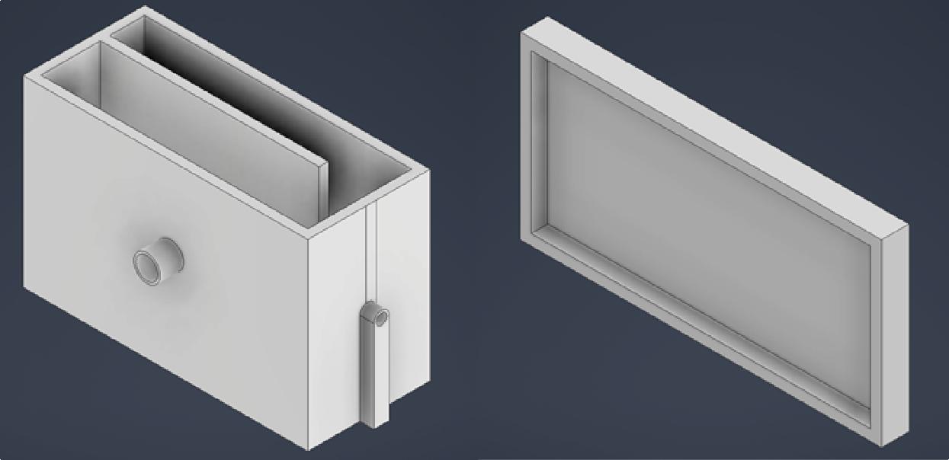
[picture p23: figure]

Overdracht document Sensorsysteem Wijk Cartesius | 23 van 56

Onderdeel 4-5a - Behuizing ontvanger (fotodiode + protoboard)
De behuizing van de ontvanger is de grootste van de twee sensorbehuizingen. Aan de zijkant zitten twee gaten met heat inserts voor bevestiging aan de sensorhouder. De voorkant heeft een verlengde loop, vergelijkbaar met een kokertje, om direct invallend zonlicht zoveel mogelijk te weren. Dit vermindert valse detecties door omgevingslicht. Binnenin is ruimte voor de powerbank, het protoboard en de bedrading. Aan de onderkant zit een uitsparing waar een schakelaar in past om het systeem van stroom te voorzien. De behuizing wordt afgesloten met een passend deksel. De behuizing van de ontvanger is te zien in Figuur 9.

Figuur 9 - Behuizing ontvanger

Onderdeel 4-5b - Behuizing zender (laser)
De behuizing van de zender lijkt sterk op die van de ontvanger en heeft dezelfde bevestigingsgaten met heat inserts aan de zijkant. Omdat er alleen een lasermodule, een powerbank en een schakelaar in zitten, is deze behuizing compacter dan die van de ontvanger. Ook deze behuizing wordt afgesloten met een passend deksel. De behuizing van de zender is te zien in Figuur 10.

Figuur 10 - Behuizing zender

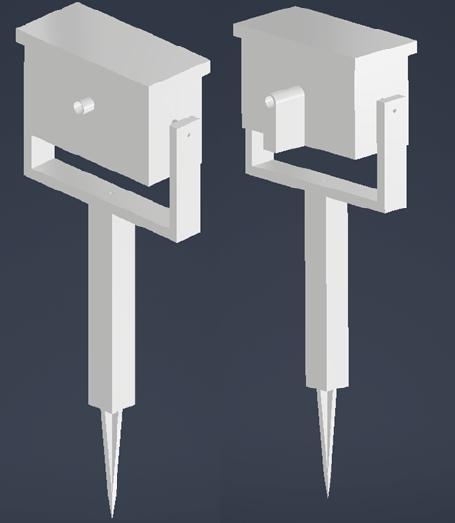
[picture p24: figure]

Overdracht document Sensorsysteem Wijk Cartesius | 24 van 56

Ontwerpiteraties
Tijdens het 3D-printen van de behuizing zijn twee onderdelen aangepast op basis van praktische problemen die ontstonden bij de eerste printpoging.

Het tussenstuk (onderdeel 2) was in het oorspronkelijke ontwerp cilindrisch van vorm. De printer had moeite met het correct printen van deze ronde geometrie, waardoor het onderdeel niet bruikbaar uit de printer kwam. Als oplossing is de vorm aangepast van cilindrisch naar vierkant. Dit maakte het onderdeel beter printbaar zonder dat de functionaliteit verloren ging.

De sensorhouder (onderdeel 3) bleek na de eerste print te dun en daardoor niet sterk genoeg om de behuizing stabiel te houden. Om dit op te lossen is de wanddikte vergroot, waardoor het onderdeel voldoende stevigheid kreeg voor gebruik in de buitenomgeving.

De definitieve versie van alle onderdelen na deze aanpassingen is te zien in Figuur 11.

Figuur 11 - Definitieve onderdelen na ontwerpiteraties

Printoverzicht behuizing
Alle onderdelen zijn geprint met PLA-filament op een Ender V3 SE. Onderstaande Tabel 3 geeft een overzicht van het materiaalverbruik en de printtijd per onderdeel.
Onderdeel | Aantal | Materiaal per stuk (PLA) | Printtijd per stuk | Printer
Onderdeel 1 - De prikker | 2x | 8 gram | 1:31 uur | Ender V3 SE
Onderdeel 2 - Het tussenstuk | 2x | 52 gram | 3:00 uur | Ender V3 SE
Onderdeel 3 - De sensorhouder | 2x | 45 gram | 4:03 uur | Ender V3 SE
Onderdeel 4a - Behuizing ontvanger | 1x | 153 gram | 14:47 uur | Ender V3 SE
Onderdeel 4b - Behuizing zender | 1x | 140 gram | 13:19 uur | Ender V3 SE
Onderdeel 5a - Deksel ontvanger | 1x | 36 gram | 2:05 uur | Ender V3 SE
Onderdeel 5b - Deksel zender | 1x | 34 gram | 1:58 uur | Ender V3 SE
Totaal | 10 prints | 573 gram | ±49:17 uur | -

Tabel 3 - Printoverzicht behuizing

Resultaat


Overdracht document Sensorsysteem Wijk Cartesius | 25 van 56

Na het printen en assembleren van alle onderdelen is het complete sensorsysteem tot stand gekomen. Onderstaande afbeelding Figuur 12 tonen het eindresultaat van zowel de zender als de ontvanger in de praktijk.

Figuur 12 - Complete opstelling zender en ontvanger

Overdracht document Sensorsysteem Wijk Cartesius | 26 van 56

## 6. Ontwikkeling van de code

### 6.1 Losse component tests

Voordat de volledige code werd geschreven, zijn alle drie de modules eerst afzonderlijk getest in aparte Arduino-sketches. Voor de fotodiode is getest of de analoge waarden correct binnenkwamen via de Serial Monitor. De RTC DS3231 is getest op correcte tijdregistratie en de SD-kaartmodule is getest op het aanmaken en wegschrijven van een testbestand. Door componenten los te testen konden fouten per module worden opgespoord zonder dat andere onderdelen storing veroorzaakten.

### 6.2 Sensor Code V1 - eerste integratie

Na de losse tests zijn alle modules samengevoegd tot één werkende code: Sensor Code V1. De belangrijkste keuzes in V1 waren:
- De fotodiode was aangesloten op digitale pin D2 en werd uitgelezen met digitalRead().
- Het logbestand had een vaste naam: LOG.CSV.
- Detectie was gebaseerd op drie patronen: een lange onderbreking voor een auto, meerdere snelle onderbrekingen voor een fietser en een korte onderbreking voor een voetganger.

### 6.3 Sensor Code V2 - verbeteringen

Tijdens het testen van V1 buiten bleek dat de fotodiode te gevoelig was voor zonlicht, waardoor het systeem continu een laser registreerde terwijl die er niet was. Dit leidde tot de volgende verbeteringen in V2:
- Overstap van digitalRead() op analogRead() op pin A3, zodat een instelbare drempelwaarde (LASER_THRESHOLD) bepaalt wanneer de laser als aanwezig wordt beschouwd.
- Toevoeging van MIN_BREAK_DURATION om ruis en trillingen te filteren: onderbrekingen korter dan 20ms worden genegeerd.
- Het logbestand krijgt automatisch een naam op basis van datum en tijd van inschakelen, zodat meerdere meetmomenten te onderscheiden zijn.
- De sensorwaarde wordt nu ook geprint in de Serial Monitor voor eenvoudiger debuggen.

De werking van V2 is schematisch weergegeven in Figuur 13.


Overdracht document Sensorsysteem Wijk Cartesius | 27 van 56

Figuur 13 - Flowchart sensor code v2

### 5.4 Sensor Code V3 - verbeterde code volgens richtlijnen

Na het ontwikkelen van V2 is de code herschreven naar V3 volgens de C-coding richtlijnen van de opleiding. De belangrijkste verbeteringen zijn:
- Alle constanten staan als #define bovenaan in hoofdletters, zodat direct zichtbaar is dat het om instellingen gaat.
- Elke functie heeft een documentatieblok met beschrijving, argumenten en returnwaarde.
- Bovenaan het bestand staat een volledige bestandsdocumentatie met naam, auteur, versie en beschrijving.
- De loop() functie bevat alleen nog functieaanroepen. Alle logica zit in aparte, herbruikbare functies.
- Globale variabelen beginnen met een g zodat direct zichtbaar is dat het globale variabelen zijn.
- Functieprototypes staan bovenaan zodat de volgorde van functies vrij is.
- Accolades staan lijnrecht onder elkaar met 4 spaties inspringing.

Overdracht document Sensorsysteem Wijk Cartesius | 28 van 56

De code is opgesplitst in de volgende functies in Tabel 4:
Functie | Beschrijving
initRTC() | Initialiseert de klokmodule
initSD() | Initialiseert de SD-kaartmodule
initLogFile() | Maakt logbestand aan met datum/tijd naam
readSensor() | Leest fotodiode en vergelijkt met drempelwaarde
handleBreakStart() | Verwerkt start van een laseronderbreking
handleBreakEnd() | Verwerkt einde van een onderbreking, filtert ruis
updateMaxDuration() | Houdt maximale breukduur bij
checkTimeout() | Controleert of evaluatiemoment bereikt is
classifyObject() | Classificeert passant als voetganger, fietser of auto
logData() | Schrijft detectie weg naar CSV op SD-kaart
resetMeting() | Reset alle variabelen voor volgende passage
Tabel 4 – Functies code

De volledige code is te zien hieronder:

/*
*
============================================================================= * Sensor_code_V3.ino
* Auteur | : Thijs Buisman
* Versie | : 3.0
* Datum | : 2026
* -----------------------------------------------------------------------------
* Beschrijving:
* | Geautomatiseerd passantenmeetsysteem voor de buitenruimte van wijk
* | Cartesius. Het systeem detecteert onderbrekingen van een laserstraal
* | via een fotodiode en classificeert passanten als voetganger, fietser
* | of auto op basis van onderbrekingspatronen. Data wordt met tijdstempel
* | weggeschreven naar een CSV-bestand op een SD-kaart.
*
* Hardware:
* | - Arduino Nano
* | - Fotodiode op pin A3 met 10kOhm pull-down weerstand
* | - RTC DS3231 op I2C (SDA=A4, SCL=A5)
* | - SD-kaartmodule op SPI (MOSI=D11, MISO=D12, SKC=D13, CS=D4)
*
* Versiebeheer:
* | V1 - Eerste werkende integratie, digitalRead op D2
* | V2 - analogRead op A3, drempelwaarde, dynamische bestandsnaam
* | V3 - Modulaire opbouw, C-coding richtlijnen, functieprototypes
*
============================================================================= */

#include <SPI.h>

#include <SD.h>

#include <Wire.h>

#include <RTClib.h>

Overdracht document Sensorsysteem Wijk Cartesius | 29 van 56

/* --- Pin definities --- */
#define SENSOR_PIN | A3

#define SD_CS_PIN | 4

/* --- Sensor drempelwaarden --- */
#define LASER_THRESHOLD | 25 | /* Analoge waarde waarboven laser aanwezig

is */
#define MIN_BREAK_DURATION 20 | /* Minimale breukduur in ms, korter =

ruis | */

/* --- Detectie instellingen --- */
#define CAR_MIN_DURATION | 800 | /* Breukduur > 800ms =

auto | */
#define BIKE_MIN_INTERRUPTS 4 | /* 4 of meer breuken =

fietser | */
#define TIMEOUT_MS | 1500 /* Wachttijd na laatste breuk voor

evaluatie | */

/* --- Overige instellingen --- */
#define SENSOR_ID "0x001b"

#define CSV_HEADER "SensorID;Datum;Tijd;GedetecteerdObject"

/* --- Globale variabelen --- */
RTC_DS3231 | rtc;
char | gLogFile[13];
bool | gIsMeasuring;
bool | gLastSensorState;
unsigned long gCurrentLowStart; unsigned long gMaxLowDuration; unsigned long gLastInterruptTime;
int | gBreakCount;

/* --- Functieprototypes --- */
void | initRTC(void);
void | initSD(void);
void | initLogFile(void);
bool | readSensor(void);
void | handleBreakStart(unsigned long currentTime);
void | handleBreakEnd(unsigned long currentTime);
void | updateMaxDuration(unsigned long currentTime);
bool | checkTimeout(unsigned long currentTime);
String classifyObject(void);
void | logData(String type);
void | resetMeting(void);

/*
* setup()
* Initialiseert alle hardware modules bij opstarten. * Wordt eenmalig uitgevoerd na inschakelen of reset. */

Overdracht document Sensorsysteem Wijk Cartesius | 30 van 56

void setup()
{
Serial.begin(9600);
gIsMeasuring | = false;
gLastSensorState | = HIGH;
gCurrentLowStart | = 0;
gMaxLowDuration | = 0;
gLastInterruptTime = 0;
gBreakCount | = 0;
initRTC();
initSD();
initLogFile();
Serial.println("Systeem klaar voor detectie."); }

/*
* loop()
* Hoofdlus: leest sensor, verwerkt flanken en evalueert na timeout. */
void loop()
{
bool | currentSensorState = readSensor();
unsigned long currentTime | = millis();

if (gLastSensorState == HIGH && currentSensorState == LOW) handleBreakStart(currentTime);

if (gLastSensorState == LOW && currentSensorState == HIGH) handleBreakEnd(currentTime);

if (gIsMeasuring && currentSensorState == LOW) updateMaxDuration(currentTime);

if (gIsMeasuring && currentSensorState == HIGH && checkTimeout(currentTime))
{
String objectType = classifyObject(); logData(objectType);
resetMeting();
}

gLastSensorState = currentSensorState; }

/*
* initRTC()
* Initialiseert de RTC DS3231 klokmodule via I2C.
* Bij stroomverlies wordt tijd ingesteld op compileer-tijdstip. */
void initRTC(void)

Overdracht document Sensorsysteem Wijk Cartesius | 31 van 56

{
if (!rtc.begin())
{
Serial.println("FOUT: RTC niet gevonden!"); while (1);
}
if (rtc.lostPower())
{
Serial.println("RTC: stroom verloren, tijd hersteld."); rtc.adjust(DateTime(F(__DATE__), F(__TIME__)));
}
}

/*
* initSD()
* Initialiseert de SD-kaartmodule via SPI.
* Stopt het programma als de module niet gevonden wordt. */
void initSD(void)
{
Serial.print("SD-kaart initialiseren..."); if (!SD.begin(SD_CS_PIN))
{
Serial.println(" MISLUKT!");
while (1);
}
Serial.println(" gelukt.");
}

/*
* initLogFile()
* Maakt logbestand aan met naam op basis van datum en tijd. * Bestandsnaam formaat: MMDDHHII.CSV (FAT32 max 8.3)
*/
void initLogFile(void)
{
DateTime now = rtc.now();
sprintf(gLogFile, "%02d%02d%02d%02d.CSV", now.month(), now.day(), now.hour(), now.minute()); Serial.print("Logbestand: "); Serial.println(gLogFile);
if (!SD.exists(gLogFile))
{
File logFile = SD.open(gLogFile, FILE_WRITE); if (logFile)
{
logFile.println(CSV_HEADER); logFile.close();
}
}

Overdracht document Sensorsysteem Wijk Cartesius | 32 van 56

}

/*
* readSensor()
* Leest analoge waarde fotodiode, vergelijkt met drempelwaarde. * Returnvalue: TRUE als laser aanwezig, FALSE als onderbroken */
bool readSensor(void)
{
int waarde = analogRead(SENSOR_PIN);
return (waarde > LASER_THRESHOLD) ? HIGH : LOW; }

/*
* handleBreakStart()
* Verwerkt het moment waarop de laserstraal wordt onderbroken. * Arguments: currentTime - huidige millis() waarde
*/
void handleBreakStart(unsigned long currentTime)
{
if (!gIsMeasuring)
{
gIsMeasuring | = true;
gBreakCount | = 0;
gMaxLowDuration = 0;
}
gBreakCount++;
gCurrentLowStart = currentTime; gLastInterruptTime = currentTime; }

/*
* handleBreakEnd()
* Verwerkt het moment waarop de laserstraal herstelt.
* Breuken korter dan MIN_BREAK_DURATION worden als ruis genegeerd. * Arguments: currentTime - huidige millis() waarde
*/
void handleBreakEnd(unsigned long currentTime)
{
if (!gIsMeasuring)
return;

unsigned long lowDuration = currentTime - gCurrentLowStart;

if (lowDuration >= MIN_BREAK_DURATION)
{
if (lowDuration > gMaxLowDuration) gMaxLowDuration = lowDuration; gLastInterruptTime = currentTime; }

Overdracht document Sensorsysteem Wijk Cartesius | 33 van 56

else
gBreakCount--;
}

/*
* updateMaxDuration()
* Houdt maximale breukduur bij tijdens actieve onderbreking. * Arguments: currentTime - huidige millis() waarde
*/
void updateMaxDuration(unsigned long currentTime)
{
unsigned long currentDuration = currentTime - gCurrentLowStart; if (currentDuration > gMaxLowDuration)
gMaxLowDuration = currentDuration;
}

/*
* checkTimeout()
* Controleert of wachttijd na laatste breuk verstreken is. * Returnvalue: TRUE als timeout bereikt, anders FALSE
* Arguments: currentTime - huidige millis() waarde
*/
bool checkTimeout(unsigned long currentTime)
{
return (currentTime - gLastInterruptTime > TIMEOUT_MS); }

/*
* classifyObject()
* Classificeert gedetecteerd object op basis van breukpatroon. * Returnvalue: String "Auto", "Fietser" of "Voetganger"
*/
String classifyObject(void)
{
String objectType;

if (gMaxLowDuration > CAR_MIN_DURATION) objectType = "Auto";
else if (gBreakCount >= BIKE_MIN_INTERRUPTS) objectType = "Fietser";
else
objectType = "Voetganger";

Serial.print("Detectie: "); Serial.print(objectType);
Serial.print(" | Breuken: "); Serial.print(gBreakCount);
Serial.print(" | Max duur: "); Serial.print(gMaxLowDuration);
Serial.println("ms");

return objectType;
}

Overdracht document Sensorsysteem Wijk Cartesius | 34 van 56

/*
* logData()
* Schrijft detectieregel naar CSV-logbestand op SD-kaart. * Formaat: SensorID;Datum;Tijd;GedetecteerdObject
* Arguments: type - gedetecteerd objecttype als String */
void logData(String type)
{
DateTime now = rtc.now();
char dateBuffer[12];
char timeBuffer[10];

sprintf(dateBuffer, "%04d-%02d-%02d", now.year(), now.month(), now.day());
sprintf(timeBuffer, "%02d:%02d:%02d", now.hour(), now.minute(), now.second());

String logString = String(SENSOR_ID) + ";" + dateBuffer + ";" + timeBuffer + ";" + type;

File logFile = SD.open(gLogFile, FILE_WRITE);
if (logFile)
{
logFile.println(logString);
logFile.close();
Serial.println("Opgeslagen in: " + String(gLogFile));
}
else
Serial.println("FOUT: kan bestand niet openen: " + String(gLogFile)); }

/*
* resetMeting()
* Reset alle metvariabelen voor de volgende passage. */
void resetMeting(void)
{
gIsMeasuring = false;
}


Overdracht document Sensorsysteem Wijk Cartesius | 35 van 56

## 7. Testen & resultaten

### 7.1 Testopstelling

Op 21 mei 2026 is het sensorprototype gedurende vier uur getest in de buitenruimte van Cartesius bij de doorgang van deelgebied 2. De test vond plaats tussen 14:45 en 18:45 onder bewolkte en droge weersomstandigheden. De afstand tussen de laser en de fotodiode bedroeg circa 2 meter. Tijdens de test is één observator ter plaatse gebleven om tegelijkertijd handmatig te registreren wat er door de doorgang passeerde via de SOPARC-webapp. Op die manier kon de sensordata achteraf worden vergeleken met de handmatige tellingen.

In Figuur 14 is de testopstelling weergegeven. Links is op de satellietfoto te zien waar de sensor is neergezet bij de doorgang van deelgebied 2. In het midden is de fysieke opstelling van de sensor op locatie te zien. Rechts is de SOPARC-webapp te zien waarmee de observator tijdens de test handmatig kon registreren wat er door de doorgang passeerde door op de knoppen te drukken.

Figuur 14 - Testopstelling: locatie (links), sensoropstelling op locatie (midden) en SOPARC-webapp voor validatie (rechts)

### 7.2 Resultaten

Om de nauwkeurigheid van het prototype te kunnen beoordelen, zijn de CSV-data van de sensor en de handmatige registraties uit de SOPARC-webapp naast elkaar gelegd in een Excel-bestand. Beide datasets bevatten per passage een tijdstempel en een gebruikerstype, waardoor de registraties op volgorde vergeleken konden worden. Een screenshot van dit overzicht is te zien in Figuur 15.

Figuur 15 - Screenshot van de samengevoegde sensor- en webapp-data in Excel

Overdracht document Sensorsysteem Wijk Cartesius | 36 van 56

Uit deze vergelijking kwamen de volgende resultaten naar voren. De sensor registreerde in totaal 81 passages, de handmatige telling via de webapp telde 79 passages. De resultaten per gebruikerstype zijn weergegeven in Tabel 5 en Tabel 6.
Gebruikerstype | Aantal
Voetganger | 50
Fietser | 28
Auto | 3
Totaal | 81
Tabel 5 - Sensordata: geregistreerde passages
Gebruikerstype | Aantal
Voetganger | 47
Fietser | 32
Auto | 0
Totaal | 79
Tabel 6 - Handmatige telling via webapp: geregistreerde passages

### 7.3 Vergelijking en nauwkeurigheid

Door de twee datasets naast elkaar te leggen, kan per gebruikerstype worden bepaald hoe nauwkeurig de sensor heeft gepresteerd. Dit is weergegeven in Tabel 7.
Gebruikerstype | Sensor | Handmatig | Verschil | Afwijking
Voetganger | 50 | 47 | +3 | 6,4%
Fietser | 28 | 32 | -4 | 12,5%
Auto | 3 | 0 | +3 | —
Totaal | 81 | 79 | +2 | 2,5%
Tabel 7 - Vergelijking sensor vs. handmatige telling

Voor voetgangers en fietsers presteert de sensor redelijk goed. Het totale verschil van 2 passages op 79 geregistreerde passages komt neer op een afwijking van 2,5%, wat binnen de gestelde eis van maximaal 15% foutmarge valt. Per gebruikerstype liggen de afwijkingen echter hoger: voor voetgangers bedraagt de afwijking 6,4% en voor fietsers 12,5%. De fietserdetectie zit daarmee dicht tegen de grens van 15% aan.

De drie geregistreerde auto's verdienen extra toelichting. De handmatige observator heeft geen auto's genoteerd in de webapp, wat betekent dat de sensor deze passages fout heeft geclassificeerd. Mogelijk gaat het om fietsers of voetgangers de laser langdurig blokkeerden, waardoor de sensor dit interpreteerde als een auto. Dit is een bekend beperkingspunt van het huidige classificatiealgoritme dat uitsluitend kijkt naar de duur van de onderbreking.

De vier gemiste fietsers aan de kant van de sensor kunnen verklaard worden doordat niet alle fietsen dezelfde spaakpatronen hebben. Fietsen met weinig of dicht op elkaar staande spaken genereren minder onderbrekingen, waardoor de sensor deze soms classificeert als voetganger in plaats van fietser.

### 7.4 Toetsing aan systeemeisen

Op basis van de testresultaten kan worden beoordeeld in hoeverre het prototype voldoet aan de vooraf opgestelde systeemeisen. Dit is weergegeven in Tabel 8.
MoSCoW | Eis | Resultaat | Toelichting
Must have | Betrouwbare detectie bij minimaal 2 meter afstand | ✓ | De sensor functioneerde correct op een afstand van 1 tot 2 meter.
Must have | Elke detectie opgeslagen met correcte tijdstempel op SD-kaart | ✓ | Alle 81 passages zijn correct weggeschreven met datum en tijd.

Overdracht document Sensorsysteem Wijk Cartesius | 37 van 56
Must have | Onderscheid tussen minimaal drie gebruikerstypen | ✓ | Het systeem classificeert voetgangers, fietsers en auto's.
Must have | Minimaal 8 uur werken op powerbank van 5000 mAh | ✓ | Het systeem heeft de volledige testduur van 4 uur zonder onderbreking gefunctioneerd. De berekende batterijduur bedraagt circa 40 uur.
Should have | Betrouwbaar werken bij direct zonlicht zonder valse detecties | ✓ | De test vond plaats bij bewolkt weer. Bij eerdere tests buiten zonder kokertje traden wel valse detecties op door zonlicht. Dit is opgelost met de analoge drempelwaarde.
Should have | Foutmarge maximaal 15% ten opzichte van handmatige telling | ✓ | De totale afwijking bedraagt 2,5%. Per type: voetganger 6,4%, fietser 12,5%. Beide vallen binnen de gestelde grens.
Should have | Geen dubbeltellingen bij één passage | ✗ | Door de hold-off tijd en minimale breukduur zijn geen dubbeltellingen waargenomen. Toch zijn er 2 extra meting gemten.
Could have | Detectie van looprichting | ✗ | Niet geïmplementeerd in dit prototype. Vereist een tweede sensormodule.
Could have | Automatische export naar leesbaar CSV met kolomkoppen | ✓ | Het systeem maakt automatisch een CSV-bestand aan met kolomkoppen en een bestandsnaam op basis van datum en tijd.
Won't have | Draadloze datatransmissie | — | Buiten scope voor dit prototype.
Won't have | Realtime monitoring op afstand | — | Buiten scope voor dit prototype.
Won't have | Automatische classificatie via machine learning | — | Buiten scope voor dit prototype.

Tabel 8 - Toetsing systeemeisen

Alle must have eisen zijn behaald. Van de drie should have eisen zijn er twee behaald, waarvan de fietser detectie met 12,5% dicht tegen de gestelde grens van 15% aanligt. De enige could have eis die niet is gerealiseerd is de richting detectie, waarvoor een tweede sensormodule nodig is.

Overdracht document Sensorsysteem Wijk Cartesius | 38 van 56

## 8. Conclusie

Het sensorprototype heeft tijdens de test op 21 mei 2026 aangetoond dat geautomatiseerde passantentelling met een lasersysteem in de buitenruimte van Cartesius haalbaar is. Alle must have eisen zijn behaald en de totale foutmarge van 2,5% valt ruim binnen de gestelde grens van 15%. Het systeem heeft gedurende de volledige testperiode van vier uur zelfstandig gefunctioneerd zonder storingen of dataverlies.

Toch zijn er ook beperkingen zichtbaar geworden. De fietserdetectie zit met een afwijking van 12,5% dicht tegen de grens aan, de sensor heeft drie passages fout geclassificeerd als auto, en de eis rondom dubbeltellingen is niet volledig behaald doordat het totale aantal registraties twee hoger uitvalt dan de handmatige telling. Dit betekent dat het systeem als proof of concept werkt, maar nog niet nauwkeurig genoeg is voor zelfstandige inzet zonder handmatige controle.

Of het systeem ook betrouwbaar werkt bij direct zonlicht, regen en harde wind kon in deze testopstelling niet worden vastgesteld omdat de test plaatsvond bij bewolkt en droog weer. Voor definitieve conclusies over de betrouwbaarheid in alle weersomstandigheden is aanvullend testen nodig.

Desondanks laat dit prototype zien dat een eenvoudig en kostenefficiënt lasersysteem in staat is om met beperkte middelen betrouwbare teldata te genereren. Het vormt daarmee een solide eerste stap richting een volwaardige sensor die in de toekomst, met de aanbevolen doorontwikkelingen, zelfstandig en continu ingezet kan worden voor het meten van het gebruik van de buitenruimte in Cartesius.

## 9. Aanbeveling

### 9.1 Beperkingen van het huidige prototype

Tijdens de test zijn een aantal beperkingen naar voren gekomen die de inzetbaarheid van het huidige prototype in de praktijk beperken. Deze zijn hieronder samengevat.

De behuizing is te zwaar en te groot, waardoor het systeem instabiel wordt bij harde wind en makkelijk kan omvallen. De prikker is van kunststof, waardoor die op harde ondergrond niet goed de grond in gaat zonder eerst een gat te maken met gereedschap. Het correct richten van de laser op de fotodiode kost veel tijd en is nauwkeurig werk, wat het plaatsen van de sensor omslachtig maakt. De maximale meetafstand bedraagt circa twee meter omdat de laserbundel daarna te veel uitspreidt en de fotodiode het signaal niet meer betrouwbaar oppikt. De behuizing is niet waterdicht, waardoor meten bij regen niet mogelijk is. Het systeem kan niet onderscheiden of er meerdere personen of fietsers naast elkaar door de doorgang lopen, wat leidt tot ondertelling bij drukte. Tot slot kunnen dieren zoals katten of honden ook door de laserstraal lopen en worden dan geregistreerd als passant, wat de data kan vertekenen.
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

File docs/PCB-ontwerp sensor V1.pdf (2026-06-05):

# PCB-ontwerp sensor V1

Thijs Buisman 1855662 HU

In deze bijlage zijn zowel de schema’s als de PCB-ontwerpen van de sensor- en laserprintplaat uitgebreid uitgelegd. De schema’s zijn logisch opgebouwd in functionele blokken, waardoor de werking van het systeem duidelijk inzichtelijk is gemaakt.

De sensorprintplaat combineert nauwkeurige metingen met betrouwbare dataopslag, waarbij de scheiding tussen analoge en digitale signalen zorgvuldig is toegepast. De laserprintplaat richt zich voornamelijk op een stabiele en veilige stroomvoorziening, met extra aandacht voor thermisch gedrag en bescherming van componenten.

1. Schema ontvanger

Figuur 1

Volledige schema ontvanger

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

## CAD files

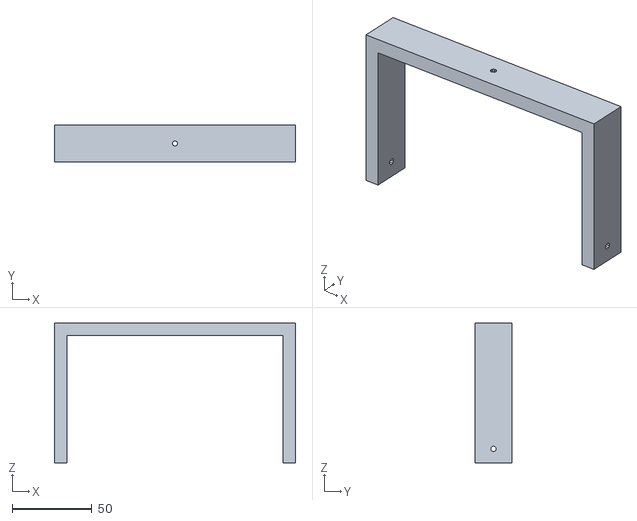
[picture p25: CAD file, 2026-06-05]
3d-ontwerp/3d-bestanden/Sensor houder V3.stl
151.5 x 23.0 x 88.0

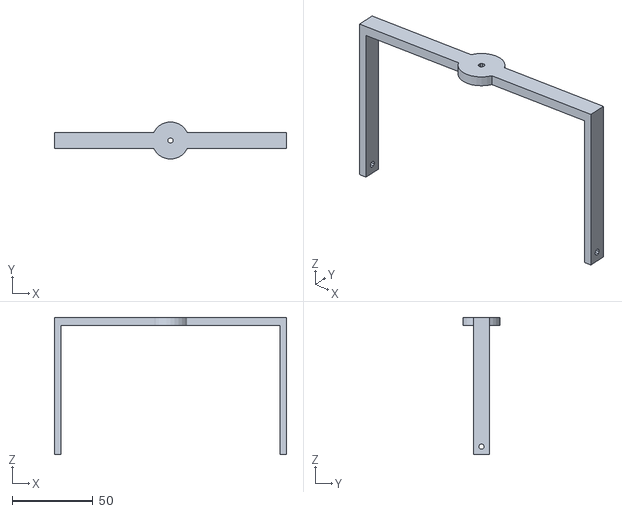
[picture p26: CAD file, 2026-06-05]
3d-ontwerp/3d-bestanden/Sensor houder.stl
143.5 x 23.0 x 85.0

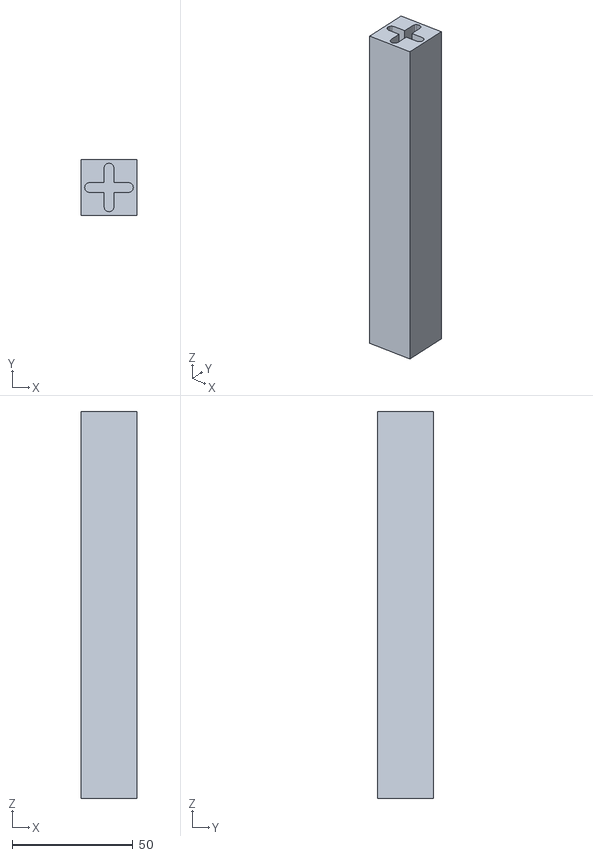
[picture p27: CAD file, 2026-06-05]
3d-ontwerp/3d-bestanden/Tussen stuk V1.2.stl
23.0 x 23.0 x 160.0

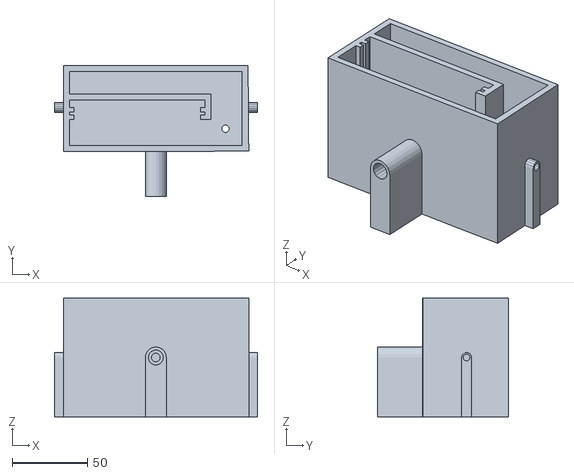
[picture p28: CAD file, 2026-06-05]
3d-ontwerp/3d-bestanden/Bakje sensor.stl
135.0 x 87.0 x 79.0

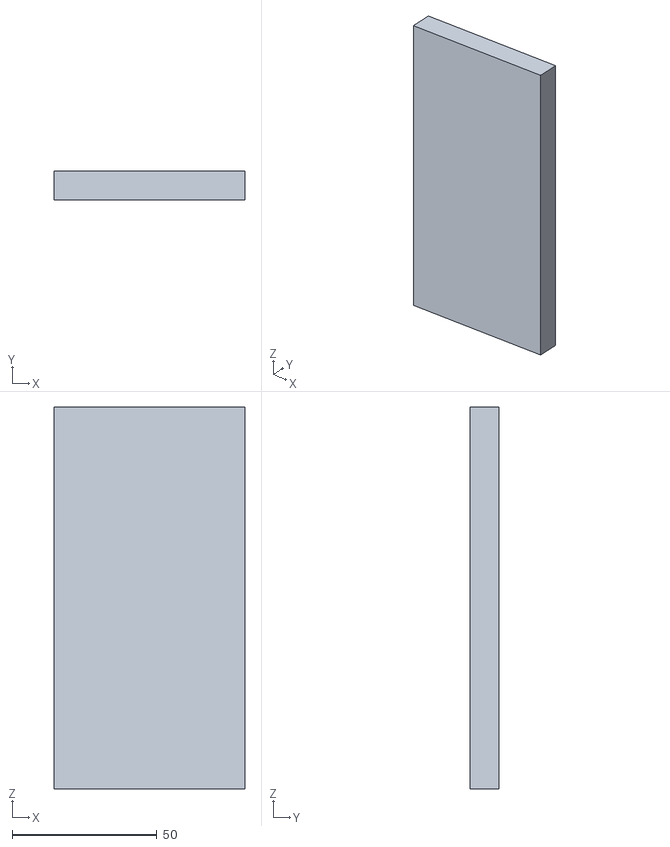
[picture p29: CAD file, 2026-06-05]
3d-ontwerp/3d-bestanden/Deksel sensor.stl
66.0 x 10.0 x 132.0

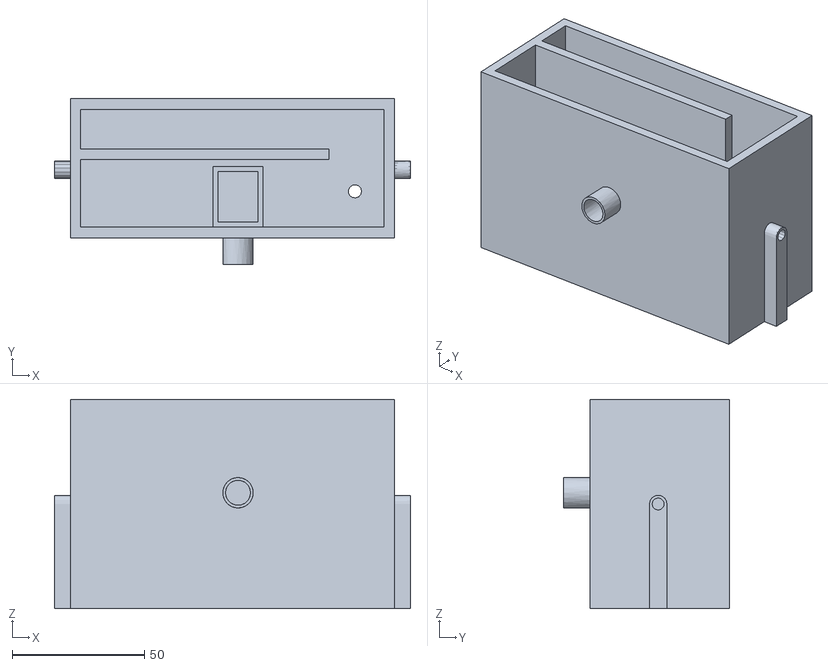
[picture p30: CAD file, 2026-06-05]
3d-ontwerp/3d-bestanden/Bakje laser.stl
134.5 x 62.5 x 79.0

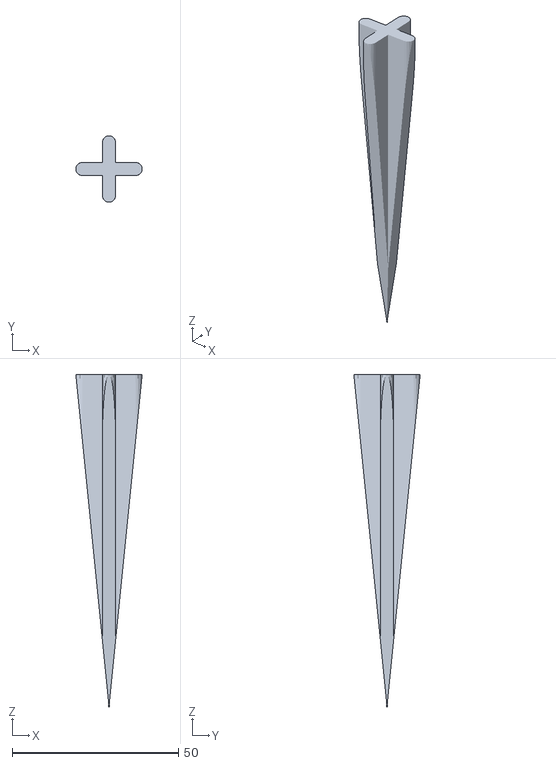
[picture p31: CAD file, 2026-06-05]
3d-ontwerp/3d-bestanden/Prikker V1.1.stl
20.0 x 20.0 x 100.0

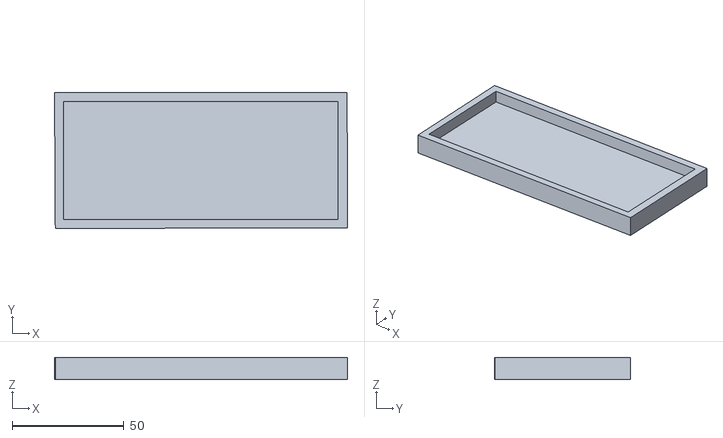
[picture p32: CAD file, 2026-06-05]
3d-ontwerp/3d-bestanden/Deksel laser.stl
131.3 x 61.0 x 10.0

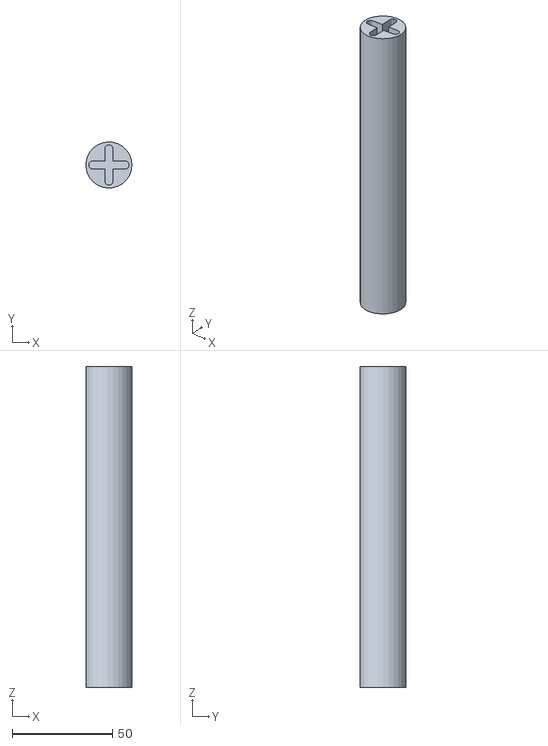
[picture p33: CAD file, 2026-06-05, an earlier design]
3d-ontwerp/3d-bestanden/Tussen stuk V1.1.stl
22.9 x 23.0 x 160.0

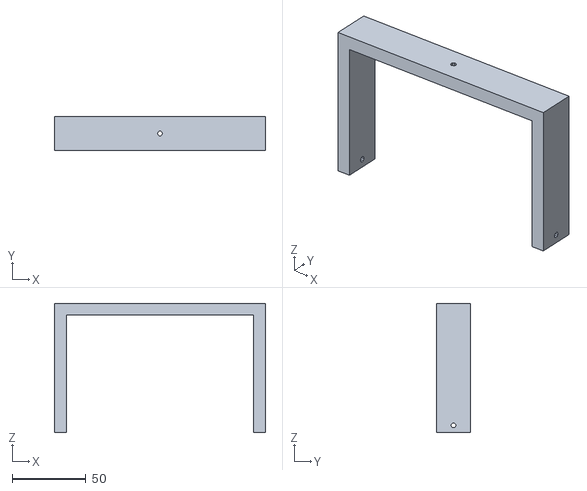
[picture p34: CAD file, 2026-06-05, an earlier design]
3d-ontwerp/3d-bestanden/Sensor houder V2.stl
143.5 x 23.0 x 88.0

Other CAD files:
3d-ontwerp/Bakje laser.ipt
3d-ontwerp/Bakje sensor.ipt
3d-ontwerp/Deksel laser.ipt
3d-ontwerp/Deksel sensor.ipt
3d-ontwerp/OldVersions/Bakje laser.0002.ipt
3d-ontwerp/OldVersions/Bakje sensor.0002.ipt
3d-ontwerp/OldVersions/Deksel laser.0001.ipt
3d-ontwerp/OldVersions/Deksel sensor.0002.ipt
3d-ontwerp/OldVersions/Ontvanger.0001.iam
3d-ontwerp/OldVersions/Prikker V1.1.0003.ipt
3d-ontwerp/OldVersions/Sensor houder.0004.ipt
3d-ontwerp/OldVersions/Tussen stuk V1.1.0005.ipt
3d-ontwerp/OldVersions/Zender.0002.iam
3d-ontwerp/Ontvanger.iam
3d-ontwerp/Prikker V1.1.ipt
3d-ontwerp/Sensor houder.ipt
3d-ontwerp/Tussen stuk V1.1.ipt
3d-ontwerp/Zender.iam

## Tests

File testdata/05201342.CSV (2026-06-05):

SensorID | Datum | Tijd | GedetecteerdObject
0x001b | 20-5-2026 | 13:45:18 | Voetganger
0x001b | 20-5-2026 | 13:47:35 | Voetganger
0x001b | 20-5-2026 | 13:49:24 | Voetganger
0x001b | 20-5-2026 | 13:51:56 | Fietser
0x001b | 20-5-2026 | 13:58:32 | Fietser
0x001b | 20-5-2026 | 14:01:52 | Voetganger
0x001b | 20-5-2026 | 14:05:22 | Voetganger
0x001b | 20-5-2026 | 14:09:41 | Fietser
0x001b | 20-5-2026 | 14:12:32 | Voetganger
0x001b | 20-5-2026 | 14:20:54 | Fietser
0x001b | 20-5-2026 | 14:22:13 | Voetganger
0x001b | 20-5-2026 | 14:30:24 | Fietser
0x001b | 20-5-2026 | 14:32:28 | Voetganger
0x001b | 20-5-2026 | 14:35:45 | Voetganger
0x001b | 20-5-2026 | 14:39:23 | Fietser
0x001b | 20-5-2026 | 14:41:13 | Fietser
0x001b | 20-5-2026 | 14:43:42 | Voetganger
0x001b | 20-5-2026 | 14:46:28 | Voetganger
0x001b | 20-5-2026 | 14:48:34 | Voetganger
0x001b | 20-5-2026 | 14:49:53 | Voetganger
0x001b | 20-5-2026 | 14:53:56 | Fietser
0x001b | 20-5-2026 | 14:57:23 | Voetganger
0x001b | 20-5-2026 | 14:59:52 | Fietser
0x001b | 20-5-2026 | 15:02:41 | Fietser
0x001b | 20-5-2026 | 15:06:12 | Voetganger
0x001b | 20-5-2026 | 15:09:32 | Voetganger
0x001b | 20-5-2026 | 15:11:42 | Fietser
0x001b | 20-5-2026 | 15:13:12 | Voetganger
0x001b | 20-5-2026 | 15:16:48 | Voetganger
0x001b | 20-5-2026 | 15:18:00 | Voetganger
0x001b | 20-5-2026 | 15:19:42 | Fietser
0x001b | 20-5-2026 | 15:21:51 | Voetganger
0x001b | 20-5-2026 | 15:25:17 | Fietser
0x001b | 20-5-2026 | 15:27:27 | Voetganger
0x001b | 20-5-2026 | 15:30:24 | Fietser
0x001b | 20-5-2026 | 15:34:26 | Voetganger
0x001b | 20-5-2026 | 15:36:46 | Fietser
0x001b | 20-5-2026 | 15:41:51 | Voetganger
0x001b | 20-5-2026 | 15:44:02 | Fietser
0x001b | 20-5-2026 | 15:49:26 | Fietser
0x001b | 20-5-2026 | 15:52:23 | Voetganger
0x001b | 20-5-2026 | 15:54:43 | Fietser
0x001b | 20-5-2026 | 15:57:47 | Fietser
0x001b | 20-5-2026 | 16:00:14 | Auto
0x001b | 20-5-2026 | 16:02:25 | Auto
0x001b | 20-5-2026 | 16:03:59 | Voetganger
0x001b | 20-5-2026 | 16:06:21 | Voetganger
0x001b | 20-5-2026 | 16:08:42 | Fietser
0x001b | 20-5-2026 | 16:09:23 | Voetganger
0x001b | 20-5-2026 | 16:15:37 | Fietser
0x001b | 20-5-2026 | 16:17:12 | Voetganger
0x001b | 20-5-2026 | 16:18:28 | Voetganger
0x001b | 20-5-2026 | 16:22:13 | Fietser
0x001b | 20-5-2026 | 16:23:59 | Voetganger
0x001b | 20-5-2026 | 16:30:43 | Voetganger
0x001b | 20-5-2026 | 16:33:38 | Auto
0x001b | 20-5-2026 | 16:35:47 | Voetganger
0x001b | 20-5-2026 | 16:40:19 | Fietser
0x001b | 20-5-2026 | 16:43:26 | Voetganger
0x001b | 20-5-2026 | 16:44:12 | Fietser
0x001b | 20-5-2026 | 16:44:47 | Fietser
0x001b | 20-5-2026 | 16:45:56 | Voetganger
0x001b | 20-5-2026 | 16:47:13 | Voetganger
0x001b | 20-5-2026 | 16:48:28 | Voetganger
0x001b | 20-5-2026 | 16:49:36 | Voetganger
0x001b | 20-5-2026 | 16:53:29 | Voetganger
0x001b | 20-5-2026 | 16:59:18 | Voetganger
0x001b | 20-5-2026 | 17:02:36 | Voetganger
0x001b | 20-5-2026 | 17:08:59 | Voetganger
0x001b | 20-5-2026 | 17:09:20 | Voetganger
0x001b | 20-5-2026 | 17:14:48 | Fietser
0x001b | 20-5-2026 | 17:18:38 | Voetganger
0x001b | 20-5-2026 | 17:22:45 | Fietser
0x001b | 20-5-2026 | 17:29:34 | Voetganger
0x001b | 20-5-2026 | 17:32:27 | Voetganger
0x001b | 20-5-2026 | 17:35:47 | Voetganger
0x001b | 20-5-2026 | 17:36:37 | Voetganger
0x001b | 20-5-2026 | 17:39:35 | Fietser
0x001b | 20-5-2026 | 17:40:12 | Fietser
0x001b | 20-5-2026 | 17:42:58 | Voetganger
0x001b | 20-5-2026 | 17:45:34 | Fietser

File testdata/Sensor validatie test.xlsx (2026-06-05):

SensorID | Datum | Tijd | GedetecteerdObject | id | button | clicked_at | zone_id
0x001b | 2026-05-20 | 13:45:18 | Voetganger | 567aa2a9-112d-4a39-80c7-c42aac4dba8d | Voetganger | 2026-05-20 13:45 | 2
0x001b | 2026-05-20 | 13:47:35 | Voetganger | f44f1852-ea84-46fa-835e-59d26ad8e5ac | Voetganger | 2026-05-20 13:47 | 2
0x001b | 2026-05-20 | 13:49:24 | Voetganger | cfa78f08-5fef-463c-9a87-982a8503dff9 | Voetganger | 2026-05-20 13:49 | 2
0x001b | 2026-05-20 | 13:51:56 | Fietser | 706fbd49-df2e-424a-b735-8102c1bd08c2 | Voetganger | 2026-05-20 13:51 | 2
0x001b | 2026-05-20 | 13:58:32 | Fietser | c542fd48-cbe8-4baf-b64a-80b35d85c760 | Fietser | 2026-05-20 13:58 | 2
0x001b | 2026-05-20 | 14:01:52 | Voetganger | 5ee1e091-ada4-4ef7-bde2-ec1fb2b9ba97 | Fietser | 2026-05-20 14:01 | 2
0x001b | 2026-05-20 | 14:05:22 | Voetganger | 193c4817-bbe9-4a68-a5f0-fae80039dd29 | Voetganger | 2026-05-20 14:05 | 2
0x001b | 2026-05-20 | 14:09:41 | Fietser | 8ede864e-82a1-47bc-ae5b-9cbd805db248 | Fietser | 2026-05-20 14:09 | 2
0x001b | 2026-05-20 | 14:12:32 | Voetganger | e97affa3-0570-402b-bb2d-df18b90abf6d | Voetganger | 2026-05-20 14:12 | 2
0x001b | 2026-05-20 | 14:20:54 | Fietser | 7f69af5a-1159-4334-a709-0708e31269d2 | Fietser | 2026-05-20 14:20 | 2
0x001b | 2026-05-20 | 14:22:13 | Voetganger | 87e7b247-75cb-430a-8974-a7a561a49124 | Voetganger | 2026-05-20 14:22 | 2
0x001b | 2026-05-20 | 14:30:24 | Fietser | b1db70b1-03d6-4aa1-9496-a4bb0fca718e | Voetganger | 2026-05-20 14:30 | 2
0x001b | 2026-05-20 | 14:32:28 | Voetganger | d558eb23-bb6f-4555-a423-02c5b5b83f5b | Voetganger | 2026-05-20 14:32 | 2
0x001b | 2026-05-20 | 14:35:45 | Voetganger | 19af7d09-59f7-4699-b9f2-6ff4011077fc | Voetganger | 2026-05-20 14:35 | 2
0x001b | 2026-05-20 | 14:39:23 | Fietser | a8f4b0b1-9d89-47f8-a750-49c084feb06d | Fietser | 2026-05-20 14:39 | 2
0x001b | 2026-05-20 | 14:41:13 | Fietser | 7d3f8049-b3b7-4bb4-be73-cbac4d6924b5 | Fietser | 2026-05-20 14:41 | 2
0x001b | 2026-05-20 | 14:43:42 | Voetganger | 4e98e789-74ff-43f7-9243-55f5a79582ad | Fietser | 2026-05-20 14:43 | 2
0x001b | 2026-05-20 | 14:46:28 | Voetganger | 5ff6b57c-7055-4eaf-8971-e56990003599 | Voetganger | 2026-05-20 14:46 | 2
0x001b | 2026-05-20 | 14:48:34 | Voetganger | 49725449-1672-4844-bf2c-d7109d5c999c | Voetganger | 2026-05-20 14:48 | 2
0x001b | 2026-05-20 | 14:49:53 | Voetganger | a51a544b-3c94-4915-b611-ea8444842792 | Voetganger | 2026-05-20 14:49 | 2
0x001b | 2026-05-20 | 14:53:56 | Fietser | 48ea5002-5c7a-4420-b7a4-c5fe89b9ed49 | Fietser | 2026-05-20 14:53 | 2
0x001b | 2026-05-20 | 14:57:23 | Voetganger | 81ab5dd5-42e1-49f3-aa4d-990bf59f4e53 | Voetganger | 2026-05-20 14:57 | 2
0x001b | 2026-05-20 | 14:59:52 | Fietser | f03b95ef-e2e7-49bc-965a-9ea5ef643919 | Fietser | 2026-05-20 14:59 | 2
0x001b | 2026-05-20 | 15:02:41 | Fietser | c5a2a66b-8789-4417-a693-0b4179ffacaa | Fietser | 2026-05-20 15:02 | 2
0x001b | 2026-05-20 | 15:06:12 | Voetganger | 34cb6d60-7607-49d8-8209-44a99928b35d | Voetganger | 2026-05-20 15:06 | 2
0x001b | 2026-05-20 | 15:09:32 | Voetganger | fd0a07e2-32de-47ad-89ec-5a5d9031ead9 | Voetganger | 2026-05-20 15:09 | 2
0x001b | 2026-05-20 | 15:11:42 | Fietser | 7af14cb1-1060-4f8b-b884-4b4cb8c91590 | Fietser | 2026-05-20 15:11 | 2
0x001b | 2026-05-20 | 15:13:12 | Voetganger | 874ead66-5e26-4145-b976-3f49eedf7e38 | Voetganger | 2026-05-20 15:13 | 2
0x001b | 2026-05-20 | 15:16:48 | Voetganger | 37a41060-b253-4e02-85da-7a520f2aa74f | Voetganger | 2026-05-20 15:16 | 2
0x001b | 2026-05-20 | 15:18:00 | Voetganger | c650f85a-e7ad-4245-ad19-93821084ac62 | Voetganger | 2026-05-20 15:18 | 2
0x001b | 2026-05-20 | 15:19:42 | Fietser | 16e3b220-dc5c-4913-b992-76d09b56b1d0 | Fietser | 2026-05-20 15:19 | 2
0x001b | 2026-05-20 | 15:21:51 | Voetganger | 8b6ee9ff-09d9-46fe-afae-8cfc163ddfb7 | Voetganger | 2026-05-20 15:21 | 2
0x001b | 2026-05-20 | 15:25:17 | Fietser | 9aeb9f27-f7fd-44a4-8502-02badcecff99 | Fietser | 2026-05-20 15:25 | 2
0x001b | 2026-05-20 | 15:27:27 | Voetganger | 9ec9467a-c51e-4269-87df-392662254d08 | Voetganger | 2026-05-20 15:27 | 2
0x001b | 2026-05-20 | 15:30:24 | Fietser | ec081778-5248-43d2-bc3d-866a9f766fe8 | Fietser | 2026-05-20 15:30 | 2
0x001b | 2026-05-20 | 15:34:26 | Voetganger | 2b65ae3e-94f5-4734-94c6-bcdd1e4b0c01 | Voetganger | 2026-05-20 15:34 | 2
0x001b | 2026-05-20 | 15:36:46 | Fietser | b27198e2-3fd4-4315-a562-9e42a8c4f8fe | Fietser | 2026-05-20 15:36 | 2
0x001b | 2026-05-20 | 15:41:51 | Voetganger | 7585f235-7e8c-410b-b158-a04a7439807c | Voetganger | 2026-05-20 15:41 | 2
0x001b | 2026-05-20 | 15:44:02 | Fietser | dd3ac1fe-d857-478a-88eb-6aa148a23ece | Fietser | 2026-05-20 15:44 | 2
0x001b | 2026-05-20 | 15:49:26 | Fietser | eb5d2cbf-7648-4836-8dc3-9ddc72b1c24f | Fietser | 2026-05-20 15:49 | 2
0x001b | 2026-05-20 | 15:52:23 | Voetganger | 6c3dbfb0-f973-45f8-bf1d-4cb1502c38df | Voetganger | 2026-05-20 15:52 | 2
0x001b | 2026-05-20 | 15:54:43 | Fietser | 701aded7-f65b-4783-9333-941c721ad99e | Fietser | 2026-05-20 15:54 | 2
0x001b | 2026-05-20 | 15:57:47 | Fietser | 7d318464-bfd3-402f-aa2b-e93e134b7e74 | Fietser | 2026-05-20 15:57 | 2
0x001b | 2026-05-20 | 16:00:14 | Auto | dfdffafe-0c36-4793-9209-30b1ae946e2a | Voetganger | 2026-05-20 16:00 | 2
0x001b | 2026-05-20 | 16:02:25 | Auto | 895b4753-fa28-4129-a45a-6330ed67620b | Voetganger | 2026-05-20 16:03 | 2
0x001b | 2026-05-20 | 16:03:59 | Voetganger | cdae53ad-9297-4e90-ae68-6ee2bca461c2 | Voetganger | 2026-05-20 16:06 | 2
0x001b | 2026-05-20 | 16:06:21 | Voetganger | 093d1453-a1a0-4501-bf82-2dc83d3c703b | Fietser | 2026-05-20 16:08 | 2
0x001b | 2026-05-20 | 16:08:42 | Fietser | 48424398-6161-418a-8963-c7ff53548ac6 | Voetganger | 2026-05-20 16:09 | 2
0x001b | 2026-05-20 | 16:09:23 | Voetganger | 38eb9fd4-4f1e-48af-8b49-8dc758abc57d | Fietser | 2026-05-20 16:15 | 2
0x001b | 2026-05-20 | 16:15:37 | Fietser | d5f36172-768b-4d84-9e94-f4bdd2c85a46 | Fietser | 2026-05-20 16:17 | 2
0x001b | 2026-05-20 | 16:17:12 | Voetganger | c9d18d13-1fd9-4964-a836-7465c11dfe5d | Voetganger | 2026-05-20 16:18 | 2
0x001b | 2026-05-20 | 16:18:28 | Voetganger | 90434f18-c24d-4a7d-a7c4-cccd30920e59 | Fietser | 2026-05-20 16:22 | 2
0x001b | 2026-05-20 | 16:22:13 | Fietser | b143908e-ebaa-4c41-ba14-9cbf9638b399 | Voetganger | 2026-05-20 16:23 | 2
0x001b | 2026-05-20 | 16:23:59 | Voetganger | 007ce23c-4b7c-4ae9-8317-39518bf99b43 | Voetganger | 2026-05-20 16:30 | 2
0x001b | 2026-05-20 | 16:30:43 | Voetganger | 7f3d0124-3ca8-43bb-ac49-c320d5d1a3db | Voetganger | 2026-05-20 16:33 | 2
0x001b | 2026-05-20 | 16:33:38 | Auto | 619dd7cc-a699-41ef-9de2-12d14890fa3d | Voetganger | 2026-05-20 16:35 | 2
0x001b | 2026-05-20 | 16:35:47 | Voetganger | 776f46dc-3491-4a0d-b0b3-8007337b1264 | Fietser | 2026-05-20 16:40 | 2
0x001b | 2026-05-20 | 16:40:19 | Fietser | bca94bf3-857c-48f9-a3f6-6823e79c7efd | Voetganger | 2026-05-20 16:43 | 2
0x001b | 2026-05-20 | 16:43:26 | Voetganger | 1ae3b678-5065-40ef-b63c-144938347d22 | Fietser | 2026-05-20 16:44 | 2
0x001b | 2026-05-20 | 16:44:12 | Fietser | 6876e385-e8c1-4ab4-a52c-87ecb9d78ee9 | Fietser | 2026-05-20 16:44 | 2
0x001b | 2026-05-20 | 16:44:47 | Fietser | dc44a728-2916-453e-973e-7e16584886e5 | Voetganger | 2026-05-20 16:45 | 2
0x001b | 2026-05-20 | 16:45:56 | Voetganger | 703a9808-67ed-49bb-982a-6cb54d1cd3a2 | Voetganger | 2026-05-20 16:47 | 2
0x001b | 2026-05-20 | 16:47:13 | Voetganger | dd762dec-2f2d-49e9-bef4-e6109b1838e9 | Voetganger | 2026-05-20 16:48 | 2
0x001b | 2026-05-20 | 16:48:28 | Voetganger | 0cd5ccbc-5191-4980-8ce7-3d5b80f0e648 | Fietser | 2026-05-20 16:49 | 2
0x001b | 2026-05-20 | 16:49:36 | Voetganger | 8de478a0-b067-4b1d-a000-b770740b1d34 | Voetganger | 2026-05-20 16:53 | 2
0x001b | 2026-05-20 | 16:53:29 | Voetganger | ae63943e-a8b7-4c1a-92e8-5e685e6d8972 | Voetganger | 2026-05-20 16:59 | 2
0x001b | 2026-05-20 | 16:59:18 | Voetganger | 8dfe688c-6962-43a8-bdec-5391260c65a1 | Fietser | 2026-05-20 17:02 | 2
0x001b | 2026-05-20 | 17:02:36 | Voetganger | 786a9efd-337a-4232-9c3c-ac8ab346a350 | Voetganger | 2026-05-20 17:08 | 2
0x001b | 2026-05-20 | 17:08:59 | Voetganger | 668a7d23-cce9-4efa-9601-181e20b0cb75 | Voetganger | 2026-05-20 17:09 | 2
0x001b | 2026-05-20 | 17:09:20 | Voetganger | 5bd9666d-2fd3-4750-85e2-a957332a3b5e | Voetganger | 2026-05-20 17:14 | 2
0x001b | 2026-05-20 | 17:14:48 | Fietser | c8c199d5-4916-4e41-a1a0-6a62a1af59a3 | Voetganger | 2026-05-20 17:18 | 2
0x001b | 2026-05-20 | 17:18:38 | Voetganger | bf5de41d-1e6a-47bc-85eb-bf7a871199e2 | Fietser | 2026-05-20 17:22 | 2
0x001b | 2026-05-20 | 17:22:45 | Fietser | 925b40e4-a2da-4d67-aa1d-e3b812202368 | Voetganger | 2026-05-20 17:29 | 2
0x001b | 2026-05-20 | 17:29:34 | Voetganger | 42f56234-b0e6-4d5d-b9ee-52dfdbdbc24e | Voetganger | 2026-05-20 17:32 | 2
0x001b | 2026-05-20 | 17:32:27 | Voetganger | 8578ec88-db40-4825-8de3-29b322617d5e | Voetganger | 2026-05-20 17:35 | 2
0x001b | 2026-05-20 | 17:35:47 | Voetganger | 732758b5-757c-4347-a1b5-081c818096bd | Fietser | 2026-05-20 17:39 | 2
0x001b | 2026-05-20 | 17:36:37 | Voetganger | 24ddf1e4-972c-4757-8137-88fd02127779 | Fietser | 2026-05-20 17:40 | 2
0x001b | 2026-05-20 | 17:39:35 | Fietser | c1745150-254d-4ba3-919a-936326f073a5 | Voetganger | 2026-05-20 17:42 | 2
0x001b | 2026-05-20 | 17:40:12 | Fietser | 80a8404c-4076-4b2e-ac4f-a84265d5c1c5 | Fietser | 2026-05-20 17:45 | 2
0x001b | 2026-05-20 | 17:42:58 | Voetganger
0x001b | 2026-05-20 | 17:45:34 | Fietser

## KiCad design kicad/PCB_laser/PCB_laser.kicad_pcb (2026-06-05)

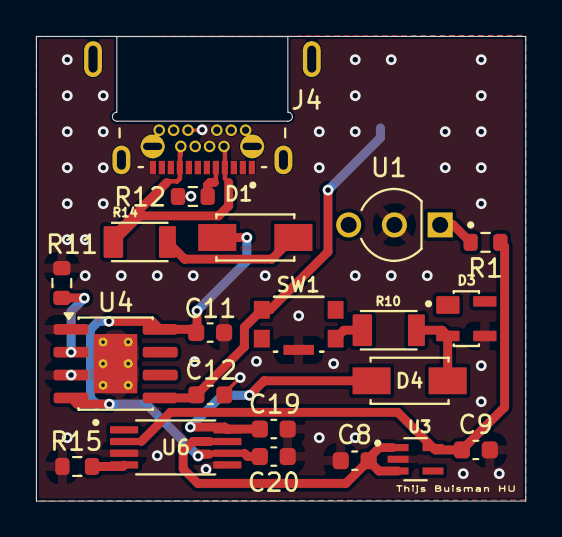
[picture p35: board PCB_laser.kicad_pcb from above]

Board: 2 copper layers, 27.2 x 25.8 mm, 22 parts (1 on the bottom side), 14 nets.

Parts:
C8, C9, C19, C20: 1uF; C_0603_1608Metric
C11, C12: 10uF; C_0603_1608Metric
D1, D4: SS14; DIOM4325X250N
D3: SP0503BAHTG; SOT143
J4: SS-52400-004; STEWART_SS-52400-004
J7: Conn_01x02; PinSocket_1x02_P2.54mm_Vertical_SMD_Pin1Right
R1: 56; R_0603_1608Metric
R10, R14: NANOSMDC016F-2; RESC3115X65N
R11: 1.2K; R_0603_1608Metric
R12: 5.1K; R_0603_1608Metric
R15: 10K; R_0603_1608Metric
SW1: KMR211GLFS; KMR2XXG_CNK
U1: D6505I; LED_SSL-LX3059IGW-CA
U3: MIC5365-3.3YC5-TR; SOT65P210X110-5N
U4: TP4056-42-ESOP8; SOIC-8-1EP_3.9x4.9mm_P1.27mm_EP2.41x3.3mm_ThermalVias
U6: TPS2115APW; SOP65P640X120-8N

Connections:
+3V3: C9.2, R1.1, U3.5 (VOUT), U6.2 (D0)
Batterij beschermd: C19.2, D4.C, U6.8 (1N1)
GND: C8.1, C9.1, C11.1, C12.2, C19.1, C20.1, D3.3, J4.B5 (CC2), J7.2, R11.2, R12.2, R15.1, SW1.5, U1.2 (COM), U3.2 (GND), U4.1 (TEMP), U4.3 (GND), U4.9 (EPAD), U6.3 (D1), U6.5 (GND)
unnamed: D1.A, R14.2
unnamed: D3.2, D4.A, R10.2
unnamed: J4.A5 (CC1), R12.1
unnamed: R10.1, SW1.4
unnamed: R1.2, U1.1 (LD-A)
unnamed: R11.1, U4.2 (PROG)
unnamed: R15.2, U6.4 (ILIM)
VBUS: J4.A4 (VBUS_A), J4.A9 (VBUS_A), J4.B4 (VBUS_B), J4.B9 (VBUS_B), R14.1
VBUS beschermd: C11.2, C20.2, D1.C, U4.4 (V_{CC}), U4.8 (CE), U6.6 (1N2)
VIN_SYS: C8.2, U3.1 (VIN), U3.3 (EN), U6.7 (OUT)
batterij+: C12.1, J7.1, SW1.1, U4.5 (BAT)

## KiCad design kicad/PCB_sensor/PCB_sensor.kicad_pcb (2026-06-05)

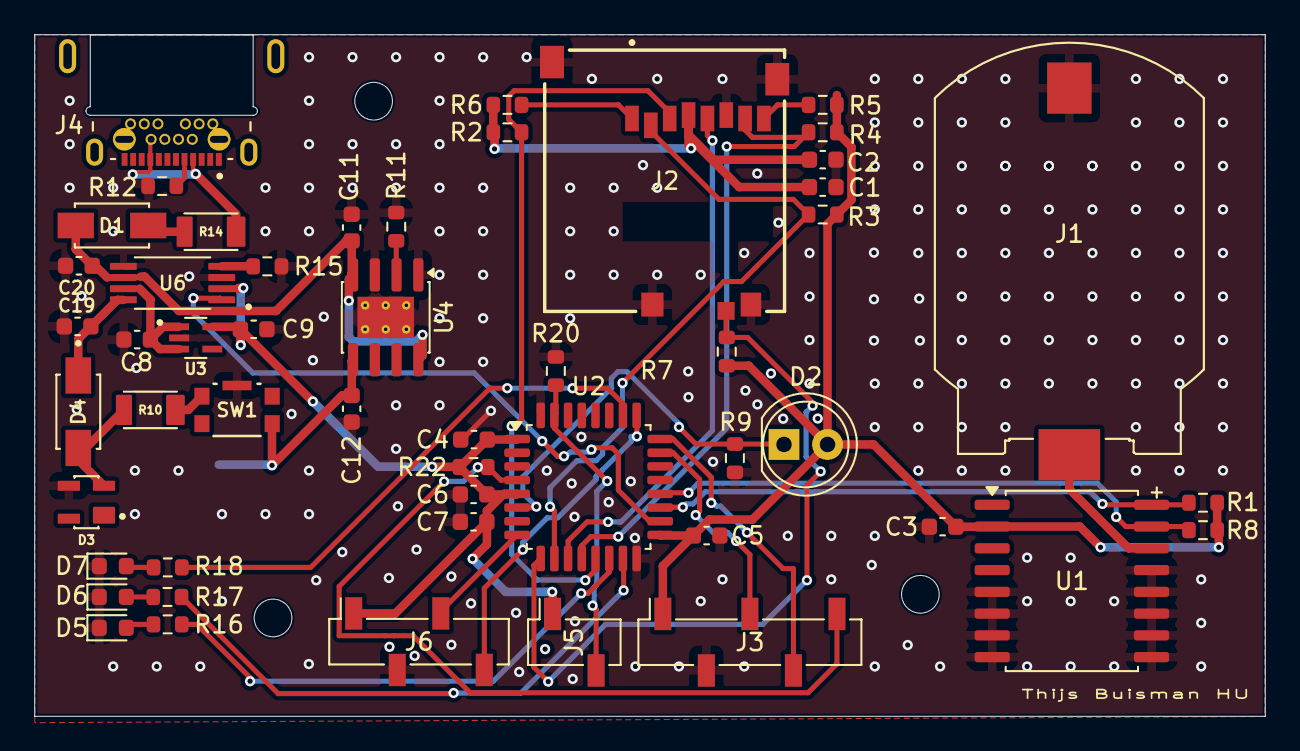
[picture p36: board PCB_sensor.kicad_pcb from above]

Board: 2 copper layers, 71.8 x 39.8 mm, 52 parts (1 on the bottom side), 37 nets.

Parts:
C1, C3, C4, C5, C6: 100nF; C_0603_1608Metric
C2, C7, C11, C12: 10uF; C_0603_1608Metric
C8, C9, C19, C20: 1uF; C_0603_1608Metric
D1, D4: SS14; DIOM4325X250N
D2: LED_D5.0mm
D3: SP0503BAHTG; SOT143
D5, D6, D7: LED; LED_0603_1608Metric
J1: S8421-45R; HARWIN_S8421-45R
J2: MEM2052-00-195-00-A_REVA; GCT_MEM2052-00-195-00-A_REVA
J3: Conn_01x05; PinSocket_1x05_P2.54mm_Vertical_SMD_Pin1Right
J4: SS-52400-004; STEWART_SS-52400-004
J5, J7: Conn_01x02; PinSocket_1x02_P2.54mm_Vertical_SMD_Pin1Right
J6: Conn_01x04; PinSocket_1x04_P2.54mm_Vertical_SMD_Pin1Right
R1, R8: 4.7K; R_0603_1608Metric
R2, R3, R4, R5, R6, R7: 10k; R_0603_1608Metric
R9, R15, R20, R22: 10K; R_0603_1608Metric
R10, R14: NANOSMDC016F-2; RESC3115X65N
R11: 1.2K; R_0603_1608Metric
R12: 5.1K; R_0603_1608Metric
R16, R17, R18: 330; R_0603_1608Metric
SW1: KMR211GLFS; KMR2XXG_CNK
U1: DS3231M; SOIC-16W_7.5x10.3mm_P1.27mm
U2: STM32L010K8Tx; LQFP-32_7x7mm_P0.8mm
U3: MIC5365-3.3YC5-TR; SOT65P210X110-5N
U4: TP4056-42-ESOP8; SOIC-8-1EP_3.9x4.9mm_P1.27mm_EP2.41x3.3mm_ThermalVias
U6: TPS2115APW; SOP65P640X120-8N

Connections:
+3V3: C1.1, C2.1, C3.2, C4.2, C5.2, C6.2, C7.2, C9.2, D2.2 (Cathode_(-)), J2.P4 (VDD), J3.1, J5.1, J6.1, R1.1, R2.1, R3.1, R4.1, R5.1, R6.1, R7.1, R8.1, R22.2, U1.2 (VCC), U2.1 (VDD), U2.5 (VDDA), U2.17 (VDD), U3.5 (VOUT), U6.2 (D0)
ADC: D2.1 (Anode_(+)), R9.1, U2.6 (PA0)
BOOT0: J5.2, R20.2, U2.31 (BOOT0)
Batterij beschermd: C19.2, D4.C, U6.8 (1N1)
Blauwe LED: R18.1, U2.26 (PB3)
CS: J2.P2 (CD/DAT3), R3.2, U2.10 (PA4)
GND: C1.2, C2.2, C3.1, C4.1, C5.1, C6.1, C7.1, C8.1, C9.1, C11.1, C12.2, C19.1, C20.1, D3.3, D5.1 (K), D6.1 (K), D7.1 (K), J1.N, J2.G1 (SHIELD_GND), J2.G2 (SHIELD_GND), J2.G3 (SHIELD_GND), J2.G4 (SHIELD_GND), J2.P6 (VSS), J3.2, J4.B5 (CC2), J6.2, J7.2, R9.2, R11.2, R12.2, R15.1, R20.1, SW1.5, U1.5 (GND), U1.6 (GND), U1.7 (GND), U1.8 (GND), U1.9 (GND), U1.10 (GND), U1.11 (GND), U1.12 (GND), U1.13 (GND), U2.16 (VSS), U2.32 (VSS), U3.2 (GND), U4.1 (TEMP), U4.3 (GND), U4.9 (EPAD), U6.3 (D1), U6.5 (GND)
Groene LED: R17.1, U2.15 (PB1)
MISO: J2.P7 (DAT0), R4.2, U2.12 (PA6)
MOSI: J2.P3 (CMD), R2.2, U2.13 (PA7)
unnamed: D1.A, R14.2
unnamed: D3.2, D4.A, R10.2
unnamed: D5.2 (A), R16.2
unnamed: D6.2 (A), R17.2
unnamed: D7.2 (A), R18.2
unnamed: J2.P8 (DAT1), R5.2
unnamed: J2.P1 (DAT2), R6.2
unnamed: J4.A5 (CC1), R12.1
unnamed: R10.1, SW1.4
unnamed: J1.P, U1.14 (VBAT)
unnamed: R11.1, U4.2 (PROG)
unnamed: R15.2, U6.4 (ILIM)
PWR_SRC_STAT: U2.18 (PA8), U6.1 (STAT)
Reset: J3.5, R22.1, U2.4 (NRST)
Rode LED: R16.1, U2.14 (PB0)
SCK: J2.P5 (CLK), U2.11 (PA5)
SCL: R1.2, U1.16 (SCL), U2.19 (PA9)
SDA: R8.2, U1.15 (SDA), U2.20 (PA10)
SDCARD: J2.P9 (CD_PIN), R7.2, U2.9 (PA3)
SWCLK: J3.4, U2.24 (PA14)
SWDIO: J3.3, U2.23 (PA13)
USART1 RX: J6.4, U2.25 (PA15)
USART1 TX: J6.3, U2.8 (PA2)
VBUS: J4.A4 (VBUS_A), J4.A9 (VBUS_A), J4.B4 (VBUS_B), J4.B9 (VBUS_B), R14.1
VBUS beschermd: C11.2, C20.2, D1.C, U4.4 (V_{CC}), U4.8 (CE), U6.6 (1N2)
VIN_SYS: C8.2, U3.1 (VIN), U3.3 (EN), U6.7 (OUT)
batterij+: C12.1, J7.1, SW1.1, U4.5 (BAT)

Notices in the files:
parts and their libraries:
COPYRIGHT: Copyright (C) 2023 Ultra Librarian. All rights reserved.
